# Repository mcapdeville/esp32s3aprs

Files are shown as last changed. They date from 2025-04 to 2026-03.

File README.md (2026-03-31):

# ESP32s3APRS

The ESP32s3APRS project aims to develop an open-source APRS (Automatic Packet Reporting System) beacon/tracker/logger, USB kiss TNC , USB audio FM tranceiver with Micropython shell based on the ESP32-S3 microcontroller.

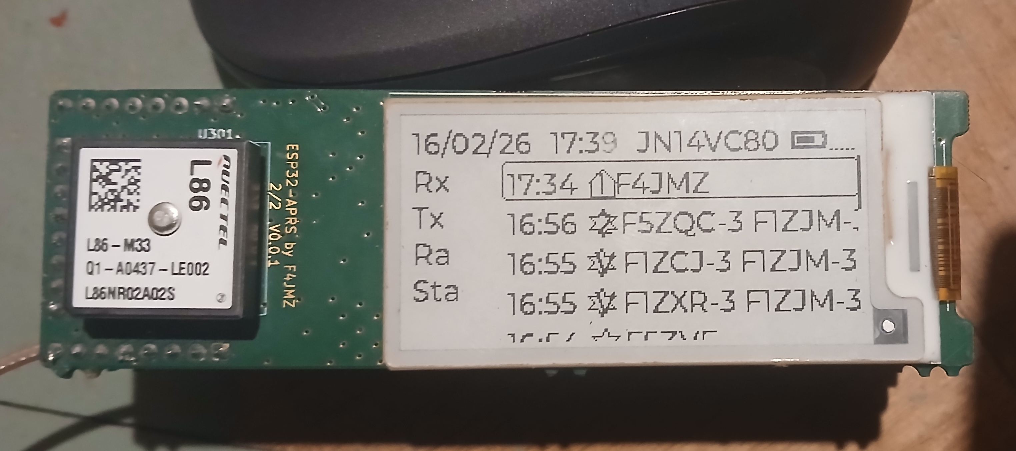
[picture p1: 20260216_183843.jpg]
ESP32s3APRS top view Top view


## Project Overview

The ESP32s3APRS is a comprehensive solution that combines hardware and software components to create a versatile packet radio. The main features include:

- **APRS and AX.25 Capabilities**: The device can transmit and receive APRS and AX.25 frames, allowing for bidirectional communication over radio.
- **USB Connectivity**: The tracker connects to a computer via USB, providing two CDC-ACM ports:
  - One port for a TNC KISS protocol interface
  - One port for a MicroPython console
- **UAC2 Audio Support**: The USB implementation includes the UAC2 protocol, enabling direct audio streaming between the device and the computer.
- **GPS**: Integrated GPS with embeded antenna.
- **Sensor Integration**: The tracker can integrate various sensors, to enrich the data transmitted over the APRS network.
- **USB-C battery charger**: can accept power input from 5v to 14V 
- **User Interface**: The device features an e-paper display and three buttons for configuration and control.
- **Power Management**: The system is designed for low power consumption, allowing for extended autonomous operation.

## Hardware Components

The ESP32s3APRS hardware consists of the following main components:

- ESP32-S3 microcontroller
- SA868 radio module
- Quectel L86 GPS receiver
- E-paper display
- 3 buttons
- USB-C battery charger

The schematic and PCB are designed with Kicad (https://www.kicad.org).
The hardware design files are distributed under the CERN-OHL-S v2 license (or later)

## Software

The software for the ESP32s3APRS is released under the GPL v3 (or later) license. It includes:

- Embedded firmware for the ESP32-S3
- APRS and AX.25 frame processing
- Data storage in flash memory
- Configuration via the user interface and MicroPython console

## Getting Started

To get started with the ESP32s3APRS project, please follow these steps:

1. Clone the repository: `git clone https://github.com/mcapdeville/esp32s3aprs.git`
2. Change to project directory: cd esp32s3aprs
3. Initialize submodules : ./init.sh

## Compile

From the project directory :

1. Load the environment variables: . ./esp-idf/export.sh
2. Compile the project: idf.py build

## Flash the device

1. Put the switch on 'Boot' position
2. Connect USB cable
3. Run: idf.py flash

## Contributing

The ESP32s3APRS project welcomes contributions from the community. You can contribute by:

- Reporting bugs or issues
- Suggesting new features or improvements
- Submitting pull requests for code or documentation changes

## License

The ESP32s3APRS software is licensed under the GPL v3 (or later) license.
The hardware design files are licensed under the CERN-OHL-S v2 license.
See the `LICENSE-GPL-V3.txt` and `LICENSE-CERN-OHL-S-V2.txt` files for more details.

## Acknowledgments

The ESP32s3APRS project was created by Marc CAPDEVILLE (F4JMZ).

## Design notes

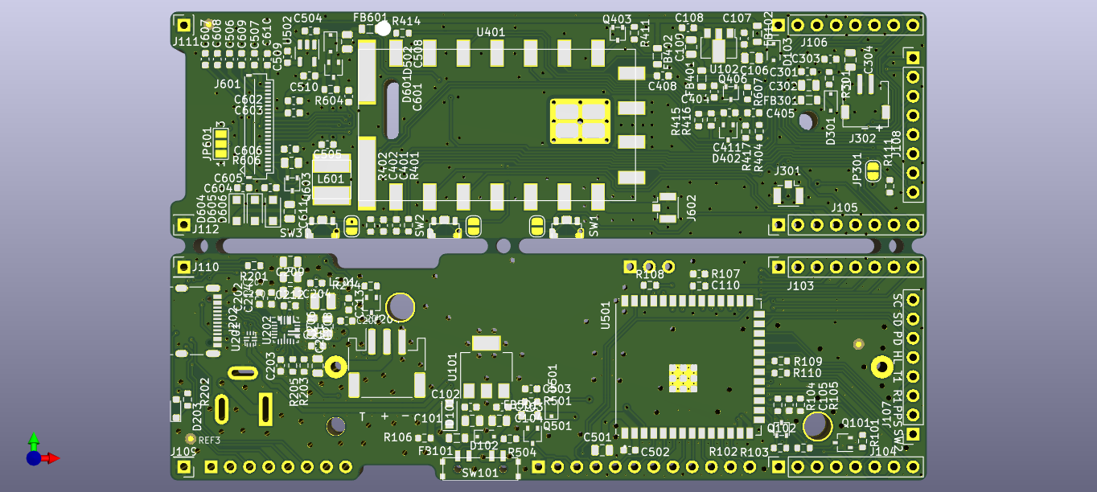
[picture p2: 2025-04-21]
hardware/ESP32s3APRS-top.png

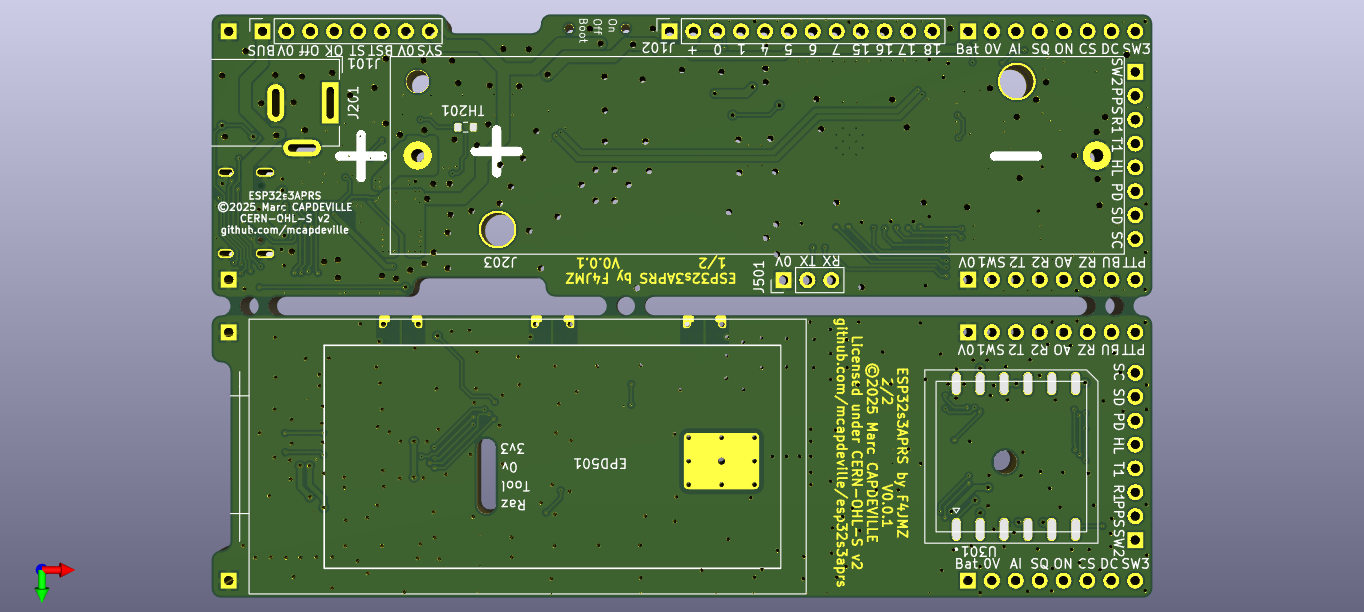
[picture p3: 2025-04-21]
hardware/ESP32s3APRS-bottom.png

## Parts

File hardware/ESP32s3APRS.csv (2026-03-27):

Reference | Qty | Value | Mouser | Radiospares | Farnell
C101,C104,C106,C109,C201,C206,C207,C208,C209,C210,C302,C304,C501 | 13 | 10µF_0805 | 963-TMK212BBJ106MG-T | 184-3756
C102,C103,C107,C108,C204,C211,C212,C213,C214,C301,C303,C404,C408,C411,C502,C504,C506,C507,C601,C603 | 20 | 100nF_0603 | 963-UMK107B7104KAHT | 184-3685
C105 | 1 | 15nF_0603 | 710-885012206090 | 839-2969
C110,C402 | 2 | 4.7nF_50V_0603 | 80-C0603C472K5R | 264-4589
C202,C203,C205 | 3 | 2.2µF_0603 | 963-UMK107BBJ225KA-T | 103-4115
C401 | 1 | 220nF_0603 | 963-UMK107B7224KAHT | 788-2997
C405 | 1 | 68nF_0603 | 710-885012206094 | 839-2978
C503,C505,C510,C602,C604,C605,C606,C607,C608,C609,C610 | 11 | 1µF_0603 | 963-UMK107BJ105KA-T | 103-4112
C508,C611 | 2 | 4.7µF_0805 | 81-GRM21BR61H475KE1L | 113-8707
C509 | 1 | 10nF_50V_0603
D101,D604,D605,D606 | 4 | SS2040FL_SOD123F | 241-SS2040FLAUR100A1
D102,D103,D301,D501,D502 | 5 | BAT54J_SOD323F | 771-BAT54J115
D203 | 1 | APA2107LZGCK | 604-APA2107LZGCK
D402,D601 | 2 | BAT54SW_SOT323 | 771-BAT54SW-T/R | 380-1216
EPD501 | 1 | GDEY0213B74
FB101,FB102,FB301,FB401,FB402,FB501,FB601 | 7 | WE-CBF_742792031 | 710-742792031 | 669-4092
J101 | 1 | SSQ-108-01-G-S | 200-SSQ10801GS
J102 | 1 | SSQ-112-01-G-S | 200-SSQ11201GS
J103,J104,J107 | 3 | SLW-108-01-G-S | 200-SLW10801GS
J105,J106,J108 | 3 | HTSW-108-07-G-S | 200-HTSW10807GS
J109,J110 | 2 | HTSW-101-07-G-S | 200-HTSW10107GS
J111,J112 | 2 | SLW-101-01-G-S | 200-SLW10101GS
J201 | 1 | WR-DC-694108301002 | 710-694108301002
J202 | 1 | USB4105-GF-A-120 | 640-USB4105-GF-A-120
J203 | 1 | Keystone_1043P | 534-1043
J204 | 1 | S3B-PH-SM4-TB | 306-S3BPHSM4TBLFSN | 688-1357
J301,J602 | 2 | U.FL-R-SMT-1 | 798-U.FL-R-SMT-110 | 557-981
J302 | 1 | S2B-ZR-SM4A-TF | 306-S2BZRSM4ATFLFSN | 762-0875 | 1830920
J501 | 1 | HTSW-103-07-G-S | 200-HTSW10307GS | 180-2117
J601 | 1 | FH34SRJ-24S-05SH | 798-FH34SRJ24S05SH99 | 136-2403
JP101,JP102,JP103 | 3 | DNP 0603
JP301 | 1 | SolderJumper_2_Open
JP601 | 1 | SolderJumper_3_Bridged12
L201 | 1 | DFE252012F-1R0M | 81-DFE252012F-1R0MP2 | 230-7900
L601 | 1 | PA4322.103NLT | 673-PA4322.103NLT
Q101,Q201,Q501 | 3 | BC846BW_SOT323 | 771-BC846BW-T/R | 436-7931
Q102,Q406 | 2 | RZF020P01TL | 755-RZF020P01TL
Q403,Q603 | 2 | RTF025N03TL | 755-RTF025N03TL
R101,R201,R204,R504 | 4 | 100K_0603 | 603-RC0603FR-07100KL | 199-5439
R102,R104,R105,R203,R205,R416,R417,R501,R604 | 9 | 10K_0603 | 603-RC0603FR-0710KL | 199-5443
R103,R411,R414 | 3 | 100R_0603 | 603-RC0603FR-07100RL | 199-5441
R106,R111 | 2 | 47K_0603 | 603-RC0603FR-0747KL | 199-5581
R107,R301,R402 | 3 | 1K_0603 | 603-RC0603FR-071KL | 199-5479
R108,R109,R110 | 3 | 470R_0603
R202 | 1 | 2K2_0603 | 603-RC0603FR-072K2L | 199-5518
R401 | 1 | 75K_0603 | 603-RC0603FR-0775KL | 199-5631
R404 | 1 | 22R_0603 | 603-RC0603FR-0722RL | 199-5504
R415 | 1 | 17K8_0603 | 603-RC0603FR-0717K8L | 122-9032
R606 | 1 | 0R47_0805 | 71-RCWE0805R470FKEA | 199-6016
R607 | 1 | R_DNP_0603
REF1,REF2,REF3 | 3 | Fiducial
SW1,SW2,SW3 | 3 | SKTDLDE010 | 688-SKTDLDE010 | 917-3839
SW101 | 1 | PCM13SMTR | 611-PCM13SMTR
TH201 | 1 | NTC 10K 1% 0603 | 594-NTCS0603E3103FMT | 684-1264
U101 | 1 | AP7361C-33E_SOT223 | 621-AP7361C-33E-13
U102 | 1 | XC6206P332PR_SOT89 | 865-XC6206P332PR-G
U201 | 1 | PI3USB102G | 729-PI3USB102GZLEX
U202 | 1 | MAX77757CEFG+ | 700-MAX77757JEFG420
U301 | 1 | L86-M33 | 277-L86-M33 | 908-4114
U401 | 1 | SA868
U501 | 1 | ESP32-S3-WROOM-1U | 356-ESP32S3WM1UN16R2
U502 | 1 | LP2985-3.3

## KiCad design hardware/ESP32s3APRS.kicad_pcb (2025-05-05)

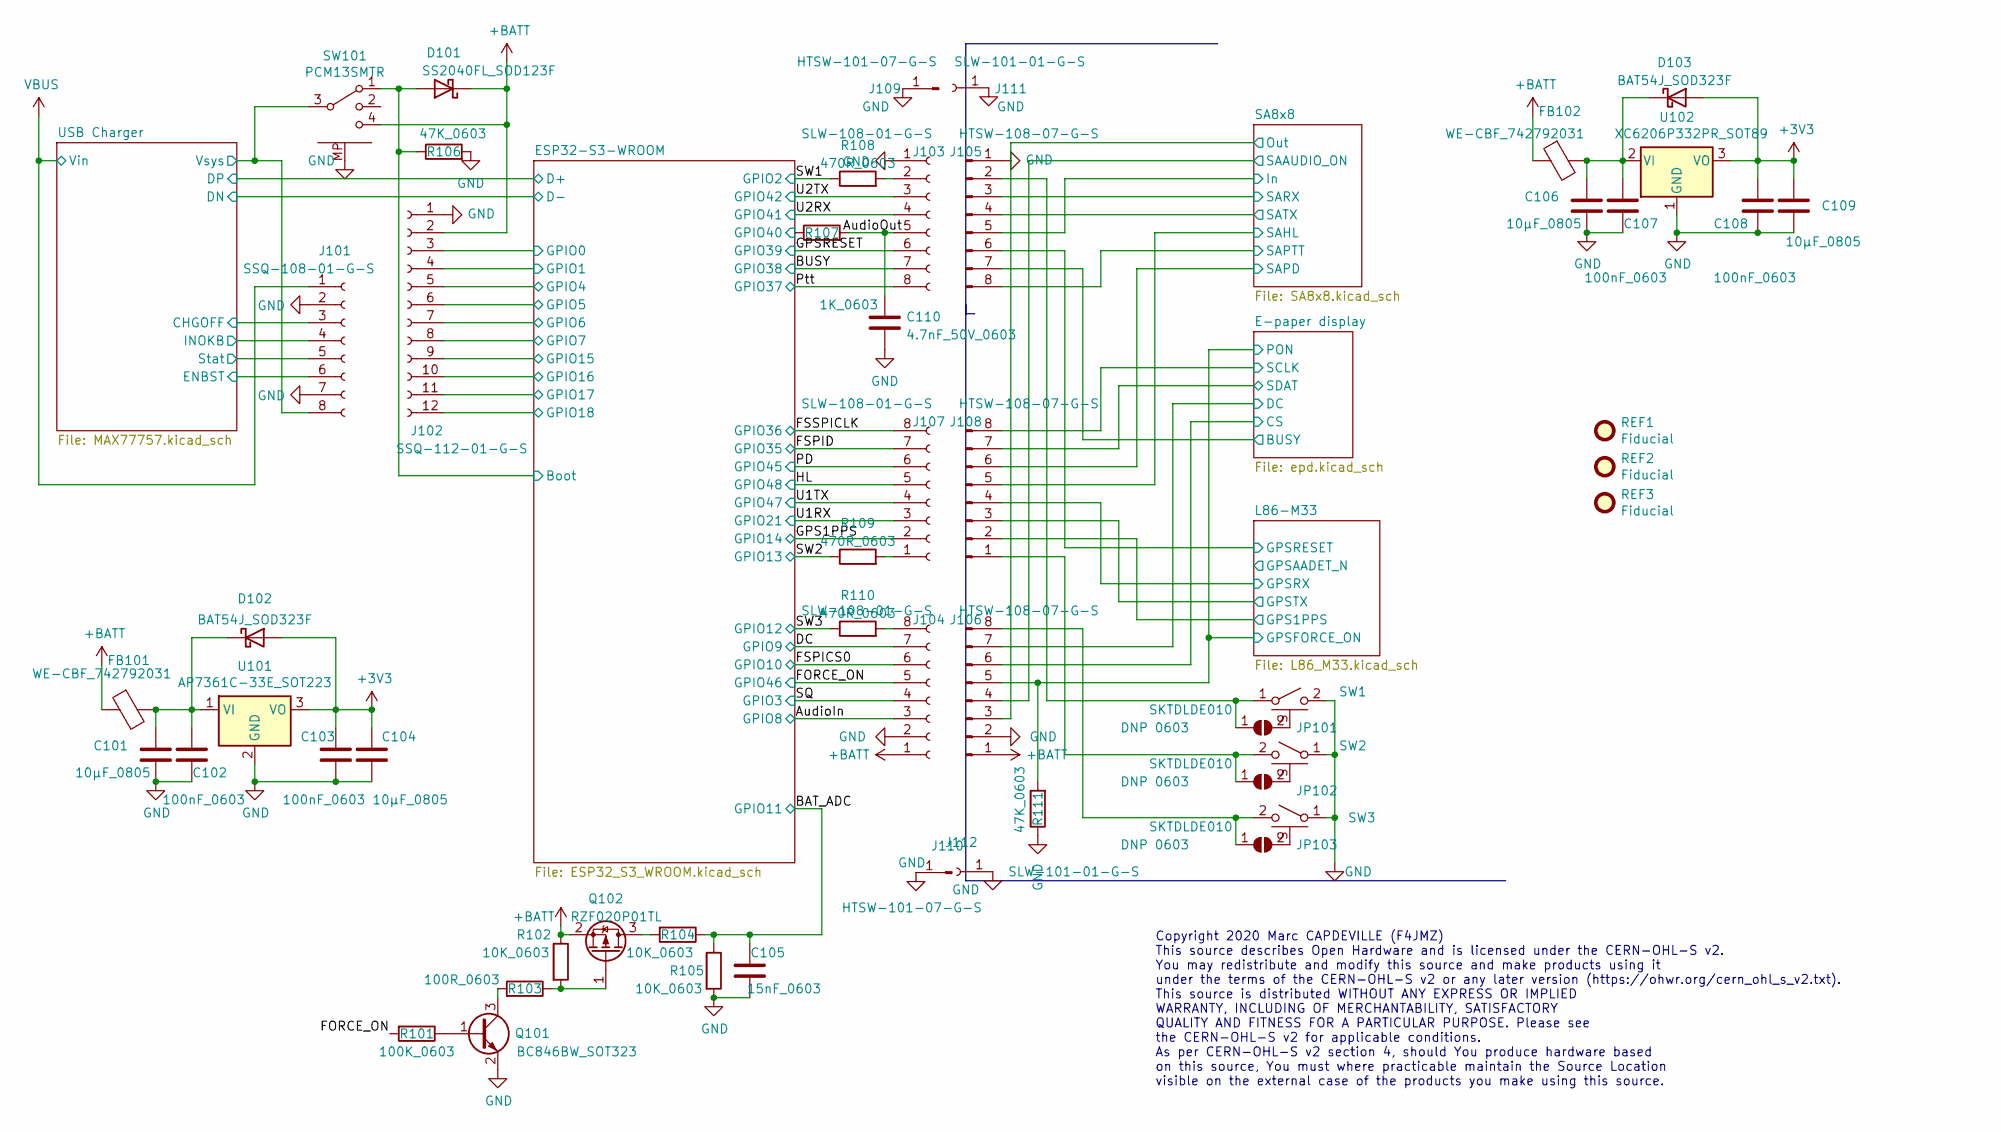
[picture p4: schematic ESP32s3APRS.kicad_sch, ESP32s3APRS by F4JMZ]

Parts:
C101, C104, C106, C109: 10µF_0805; C_0805_2012Metric; Mouser 963-TMK212BBJ106MG-T
C102, C103, C107, C108: 100nF_0603; C_0603_1608Metric; Mouser 963-UMK107B7104KAHT
C105: 15nF_0603; C_0603_1608Metric; Mouser 710-885012206090
C110: 4.7nF_50V_0603; C_0603_1608Metric; Mouser 80-C0603C472K5R
D101: SS2040FL_SOD123F; D_SOD-123F; Mouser 241-SS2040FLAUR100A1
D102, D103: BAT54J_SOD323F; D_SOD-323F; Mouser 771-BAT54J115
FB101, FB102: WE-CBF_742792031; L_0805_2012Metric; Mouser 710-742792031
J101: SSQ-108-01-G-S; PinSocket_1x08_P2.54mm_Vertical; Mouser 200-SSQ10801GS
J102: SSQ-112-01-G-S; PinSocket_1x12_P2.54mm_Vertical; Mouser 200-SSQ11201GS
J103, J104, J107: SLW-108-01-G-S; PinSocket_1x08_P2.54mm_Vertical; Mouser 200-SLW10801GS
J105, J106, J108: HTSW-108-07-G-S; PinHeader_1x08_P2.54mm_Vertical; Mouser 200-HTSW10807GS
J109, J110: HTSW-101-07-G-S; PinHeader_1x01_P2.54mm_Vertical; Mouser 200-HTSW10107GS
J111, J112: SLW-101-01-G-S; PinSocket_1x01_P2.54mm_Vertical; Mouser 200-SLW10101GS
JP101, JP102, JP103: DNP 0603; R_0603_1608Metric_Pad0.98x0.95mm_HandSolder
Q101: BC846BW_SOT323; SOT-323_SC-70; Mouser 771-BC846BW-T/R
Q102: RZF020P01TL; SOT-323T_SC-113A; Mouser 755-RZF020P01TL
R101: 100K_0603; R_0603_1608Metric; Mouser 603-RC0603FR-07100KL
R102, R104, R105: 10K_0603; R_0603_1608Metric; Mouser 603-RC0603FR-0710KL
R103: 100R_0603; R_0603_1608Metric; Mouser 603-RC0603FR-07100RL
R106, R111: 47K_0603; R_0603_1608Metric; Mouser 603-RC0603FR-0747KL
R107: 1K_0603; R_0603_1608Metric; Mouser 603-RC0603FR-071KL
R108, R109, R110: 470R_0603; R_0603_1608Metric
REF1, REF2, REF3: Fiducial; Fiducial_0.75mm_Mask1.5mm
SW1, SW2, SW3: SKTDLDE010; Mouser 688-SKTDLDE010
SW101: PCM13SMTR; SW_PCM13SMTR _SP3T; Mouser 611-PCM13SMTR
U101: AP7361C-33E_SOT223; SOT-223-3_TabPin2; Mouser 621-AP7361C-33E-13
U102: XC6206P332PR_SOT89; SOT-89-3; Mouser 865-XC6206P332PR-G

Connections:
+3V3: C103.1, C104.1, C108.1, C109.1, D102.2 (A), D103.2 (A), U101.3 (VO), U102.3 (VO); also elsewhere on the board
+BATT: D101.1 (K), FB101.1, FB102.1, J102.2, J104.1, J106.1, Q102.2 (S), R102.1, SW101.4; also elsewhere on the board
/AudioIn: J104.3; also elsewhere on the board
/BAT_ADC: C105.1, R104.1, R105.1; also elsewhere on the board
/BUSY: J103.7; also elsewhere on the board
/DC: J104.7; also elsewhere on the board
/E-paper display/BUSY: J105.7; also elsewhere on the board
/E-paper display/CS: J106.6; also elsewhere on the board
/E-paper display/DC: J106.7; also elsewhere on the board
/E-paper display/PON: J106.5, R111.2; also elsewhere on the board
/E-paper display/SCLK: J108.8; also elsewhere on the board
/E-paper display/SDAT: J108.7; also elsewhere on the board
/ESP32-S3-WROOM/Boot: D101.2 (A), R106.1, SW101.1; also elsewhere on the board
/ESP32-S3-WROOM/GPIO0: J102.3; also elsewhere on the board
/ESP32-S3-WROOM/GPIO1: J102.4; also elsewhere on the board
/ESP32-S3-WROOM/GPIO4: J102.5; also elsewhere on the board
/ESP32-S3-WROOM/GPIO5: J102.6; also elsewhere on the board
/ESP32-S3-WROOM/GPIO6: J102.7; also elsewhere on the board
/ESP32-S3-WROOM/GPIO7: J102.8; also elsewhere on the board
/ESP32-S3-WROOM/GPIO15: J102.9; also elsewhere on the board
/ESP32-S3-WROOM/GPIO16: J102.10; also elsewhere on the board
/ESP32-S3-WROOM/GPIO17: J102.11; also elsewhere on the board
/ESP32-S3-WROOM/GPIO18: J102.12; also elsewhere on the board
/ESP32-S3-WROOM/GPIO40: R107.1; also elsewhere on the board
/FORCE_ON: J104.5, R101.2; also elsewhere on the board
/FSPICS0: J104.6; also elsewhere on the board
/FSPID: J107.7; also elsewhere on the board
/FSSPICLK: J107.8; also elsewhere on the board
/GPS1PPS: J107.2; also elsewhere on the board
/GPSRESET: J103.6; also elsewhere on the board
/HL: J107.5; also elsewhere on the board
/L86-M33/GPS1PPS: J108.2; also elsewhere on the board
/L86-M33/GPSRESET: J105.6; also elsewhere on the board
/L86-M33/GPSRX: J108.4; also elsewhere on the board
/L86-M33/GPSTX: J108.3; also elsewhere on the board
/PD: J107.6; also elsewhere on the board
/Ptt: J103.8; also elsewhere on the board
/SA8x8/In: J105.5; also elsewhere on the board
/SA8x8/Out: J106.3; also elsewhere on the board
/SA8x8/SAAUDIO_ON: J106.4; also elsewhere on the board
/SA8x8/SAHL: J108.5; also elsewhere on the board
/SA8x8/SAPD: J108.6; also elsewhere on the board
/SA8x8/SAPTT: J105.8; also elsewhere on the board
/SA8x8/SARX: J105.3; also elsewhere on the board
/SA8x8/SATX: J105.4; also elsewhere on the board
/SQ: J104.4; also elsewhere on the board
/SW1: R108.1; also elsewhere on the board
/SW2: R109.1; also elsewhere on the board
/SW3: R110.1; also elsewhere on the board
/U1RX: J107.3; also elsewhere on the board
/U1TX: J107.4; also elsewhere on the board
/U2RX: J103.4; also elsewhere on the board
/U2TX: J103.3; also elsewhere on the board
/USB Charger/CHGOFF: J101.3; also elsewhere on the board
/USB Charger/ENBST: J101.6; also elsewhere on the board
/USB Charger/INOKB: J101.4; also elsewhere on the board
/USB Charger/Stat: J101.5; also elsewhere on the board
/USB Charger/Vsys: J101.8, SW101.3; also elsewhere on the board
GND: C101.2, C102.2, C103.2, C104.2, C105.2, C106.2, C107.2, C108.2, C109.2, C110.2, J101.2, J101.7, J102.1, J103.1, J104.2, J105.1, J106.2, J109.1, J110.1, J111.1, J112.1, Q101.2 (E), R105.2, R106.2, R111.1, SW1.2 (B), SW2.1 (A), SW3.1 (A), SW101.MP, U101.2 (GND), U102.1 (GND); also elsewhere on the board
unnamed: C101.1, C102.1, D102.1 (K), FB101.2, U101.1 (VI)
unnamed: C106.1, C107.1, D103.1 (K), FB102.2, U102.2 (VI)
unnamed: C110.1, J103.5, R107.2
unnamed: J103.2, R108.2
unnamed: J104.8, R110.2
unnamed: J105.2, JP101.1 (A), SW1.1 (A)
unnamed: J106.8, JP103.1 (A), SW3.2 (B)
unnamed: J107.1, R109.2
unnamed: J108.1, JP102.1 (A), SW2.2 (B)
unnamed: JP101.2 (B), SW1.S (MP)
unnamed: JP102.2 (B), SW2.S (MP)
unnamed: JP103.2 (B), SW3.S (MP)
unnamed: Q101.1 (B), R101.1
unnamed: Q101.3 (C), R103.2
unnamed: Q102.1 (G), R102.2, R103.1
unnamed: Q102.3 (D), R104.2
VBUS: J101.1; also elsewhere on the board

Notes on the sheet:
Copyright 2020 Marc CAPDEVILLE (F4JMZ) This source describes Open Hardware and is licensed under the CERN-OHL-S v2. You may redistribute and modify this source and make products using it under the terms of the CERN-OHL-S v2 or any later version (https://ohwr.org/cern_ohl_s_v2.txt). This source is d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

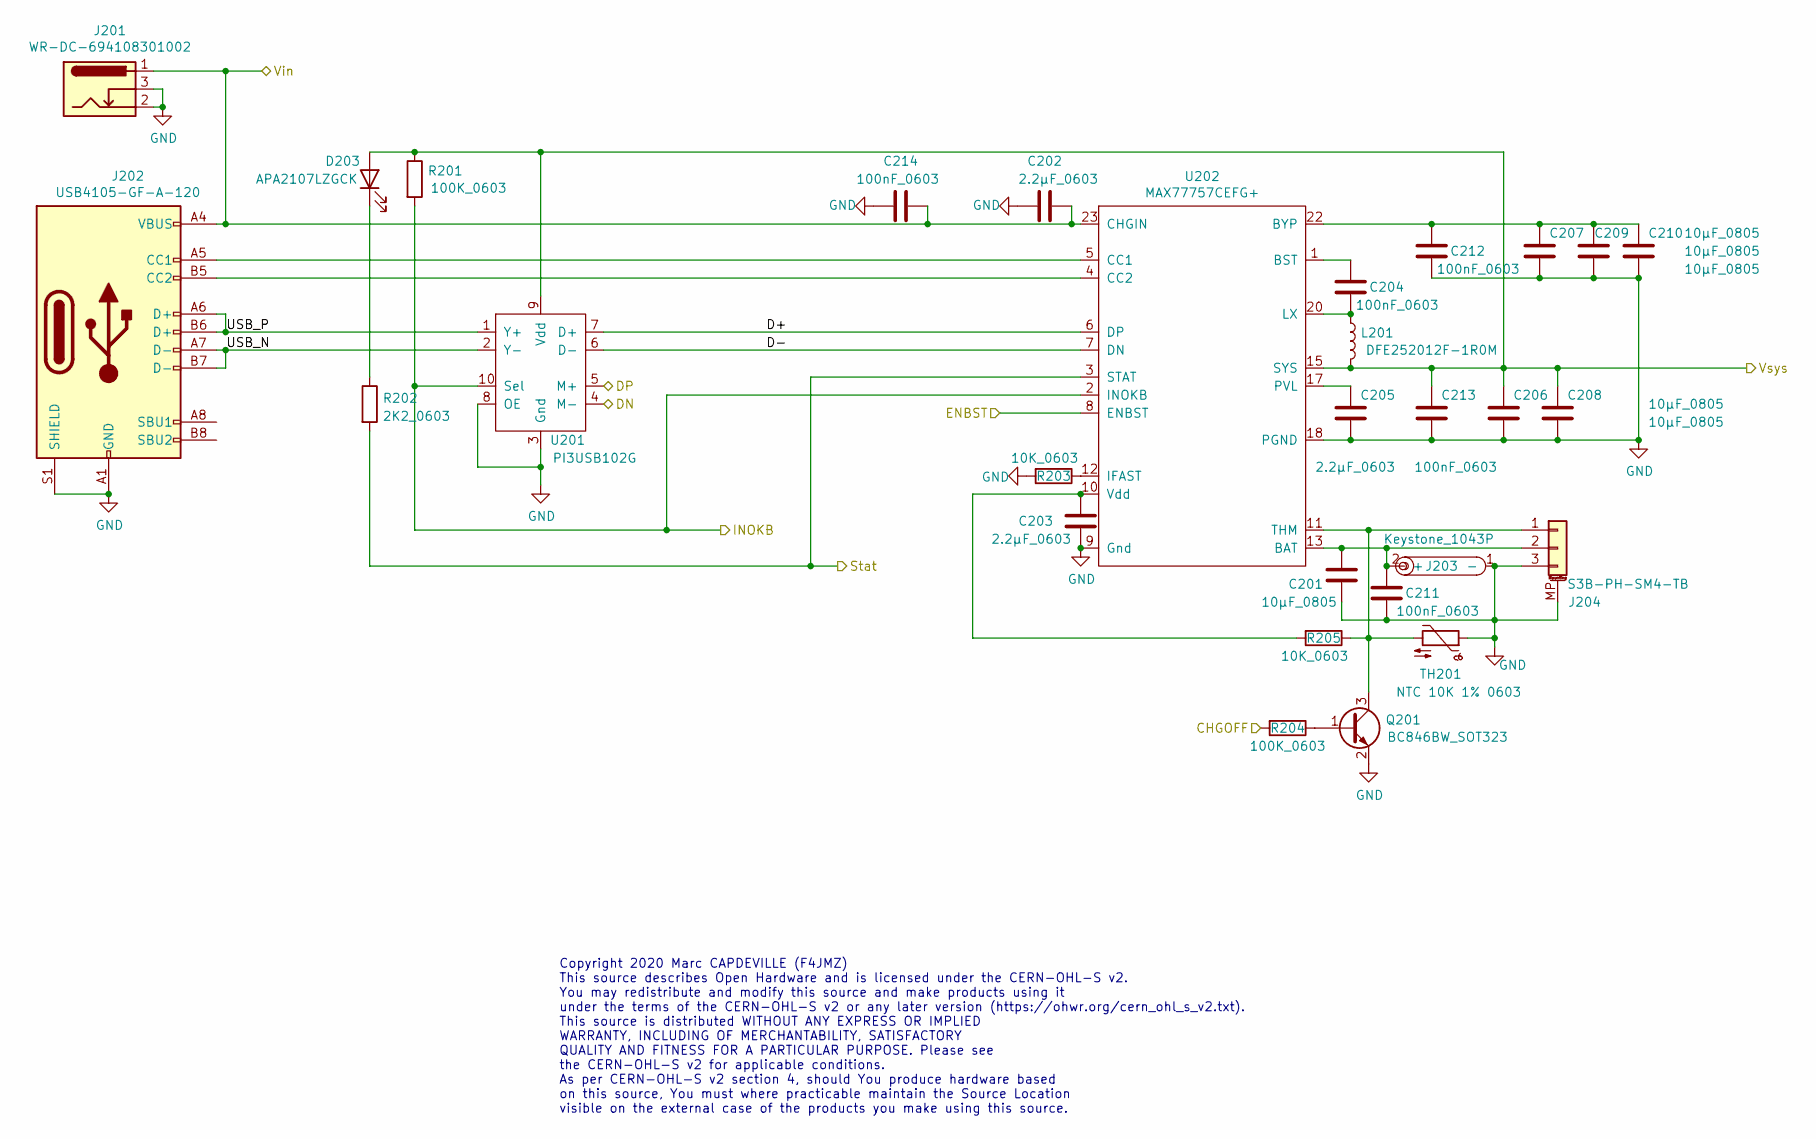
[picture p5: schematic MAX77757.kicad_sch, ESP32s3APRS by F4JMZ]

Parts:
C201, C206, C207, C208, C209, C210: 10µF_0805; C_0805_2012Metric; Mouser 963-TMK212BBJ106MG-T
C202, C203, C205: 2.2µF_0603; C_0603_1608Metric; Mouser 963-UMK107BBJ225KA-T
C204, C211, C212, C213, C214: 100nF_0603; C_0603_1608Metric; Mouser 963-UMK107B7104KAHT
D203: APA2107LZGCK; SIDELED_APA2107; Mouser 604-APA2107LZGCK
J201: WR-DC-694108301002; BarrelJack_Wuerth_6941xx301002; Mouser 710-694108301002
J202: USB4105-GF-A-120; USB_C_Receptacle_GCT_4105; Mouser 640-USB4105-GF-A-120
J203: Keystone_1043P; Keystone-1043; Mouser 534-1043
J204: S3B-PH-SM4-TB; JST_PH_S3B-PH-SM4-TB_1x03-1MP_P2.00mm_Horizontal; Mouser 306-S3BPHSM4TBLFSN
L201: DFE252012F-1R0M; L_1008_2520Metric; Mouser 81-DFE252012F-1R0MP2
Q201: BC846BW_SOT323; SOT-323_SC-70; Mouser 771-BC846BW-T/R
R201, R204: 100K_0603; R_0603_1608Metric; Mouser 603-RC0603FR-07100KL
R202: 2K2_0603; R_0603_1608Metric; Mouser 603-RC0603FR-072K2L
R203, R205: 10K_0603; R_0603_1608Metric; Mouser 603-RC0603FR-0710KL
TH201: NTC 10K 1% 0603; R_0603_1608Metric; Mouser 594-NTCS0603E3103FMT
U201: PI3USB102G; TQFN-10_1.3x1.6mm_P0.4mm; Mouser 729-PI3USB102GZLEX
U202: MAX77757CEFG+; FC2QFN-24_3x3_Pitch0.4mm; Mouser 700-MAX77757JEFG420

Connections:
/ESP32-S3-WROOM/D+: U201.5 (M+); also elsewhere on the board
/ESP32-S3-WROOM/D-: U201.4 (M-); also elsewhere on the board
/USB Charger/CHGOFF: R204.2; also elsewhere on the board
/USB Charger/D+: U201.7 (D+), U202.6 (DP)
/USB Charger/D-: U201.6 (D-), U202.7 (DN)
/USB Charger/ENBST: U202.8 (ENBST); also elsewhere on the board
/USB Charger/INOKB: R201.2, U201.10 (Sel), U202.2 (INOKB); also elsewhere on the board
/USB Charger/Stat: R202.2, U202.3 (STAT); also elsewhere on the board
/USB Charger/USB_N: J202.A7 (D-), J202.B7 (D-), U201.2 (Y-)
/USB Charger/USB_P: J202.A6 (D+), J202.B6 (D+), U201.1 (Y+)
/USB Charger/Vsys: C206.1, C208.1, C213.1, D203.2 (A), L201.2, R201.1, U201.9 (Vdd), U202.15 (SYS), U202.16 (SYS); also elsewhere on the board
GND: C201.2, C202.2, C203.2, C205.2, C206.2, C207.2, C208.2, C209.2, C210.2, C211.2, C212.2, C213.2, C214.2, J201.2, J201.3, J202.A1 (GND), J202.A12 (GND), J202.B1 (GND), J202.B12 (GND), J202.S1 (SHIELD), J203.1 (-), J204.3, J204.MP (MountPin), Q201.2 (E), R203.2, TH201.1, U201.3 (Gnd), U201.8 (OE), U202.9 (Gnd), U202.18 (PGND), U202.19 (PGND); also elsewhere on the board
unnamed: C201.1, C211.1, J203.2 (+), J204.2, U202.13 (BAT), U202.14 (BAT)
unnamed: C203.1, R205.2, U202.10 (Vdd)
unnamed: C204.1, U202.1 (BST)
unnamed: C204.2, L201.1, U202.20 (LX), U202.21 (LX)
unnamed: C205.1, U202.17 (PVL)
unnamed: C207.1, C209.1, C210.1, C212.1, U202.22 (BYP)
unnamed: D203.1 (K), R202.1
unnamed: J202.A5 (CC1), U202.5 (CC1)
unnamed: J202.B5 (CC2), U202.4 (CC2)
unnamed: J204.1, Q201.3 (C), R205.1, TH201.2, U202.11 (THM)
unnamed: Q201.1 (B), R204.1
unnamed: R203.1, U202.12 (IFAST)
VBUS: C202.1, C214.1, J201.1, J202.A4 (VBUS), J202.A9 (VBUS), J202.B4 (VBUS), J202.B9 (VBUS), U202.23 (CHGIN), U202.24 (CHGIN); also elsewhere on the board

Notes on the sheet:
Copyright 2020 Marc CAPDEVILLE (F4JMZ) This source describes Open Hardware and is licensed under the CERN-OHL-S v2. You may redistribute and modify this source and make products using it under the terms of the CERN-OHL-S v2 or any later version (https://ohwr.org/cern_ohl_s_v2.txt). This source is d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

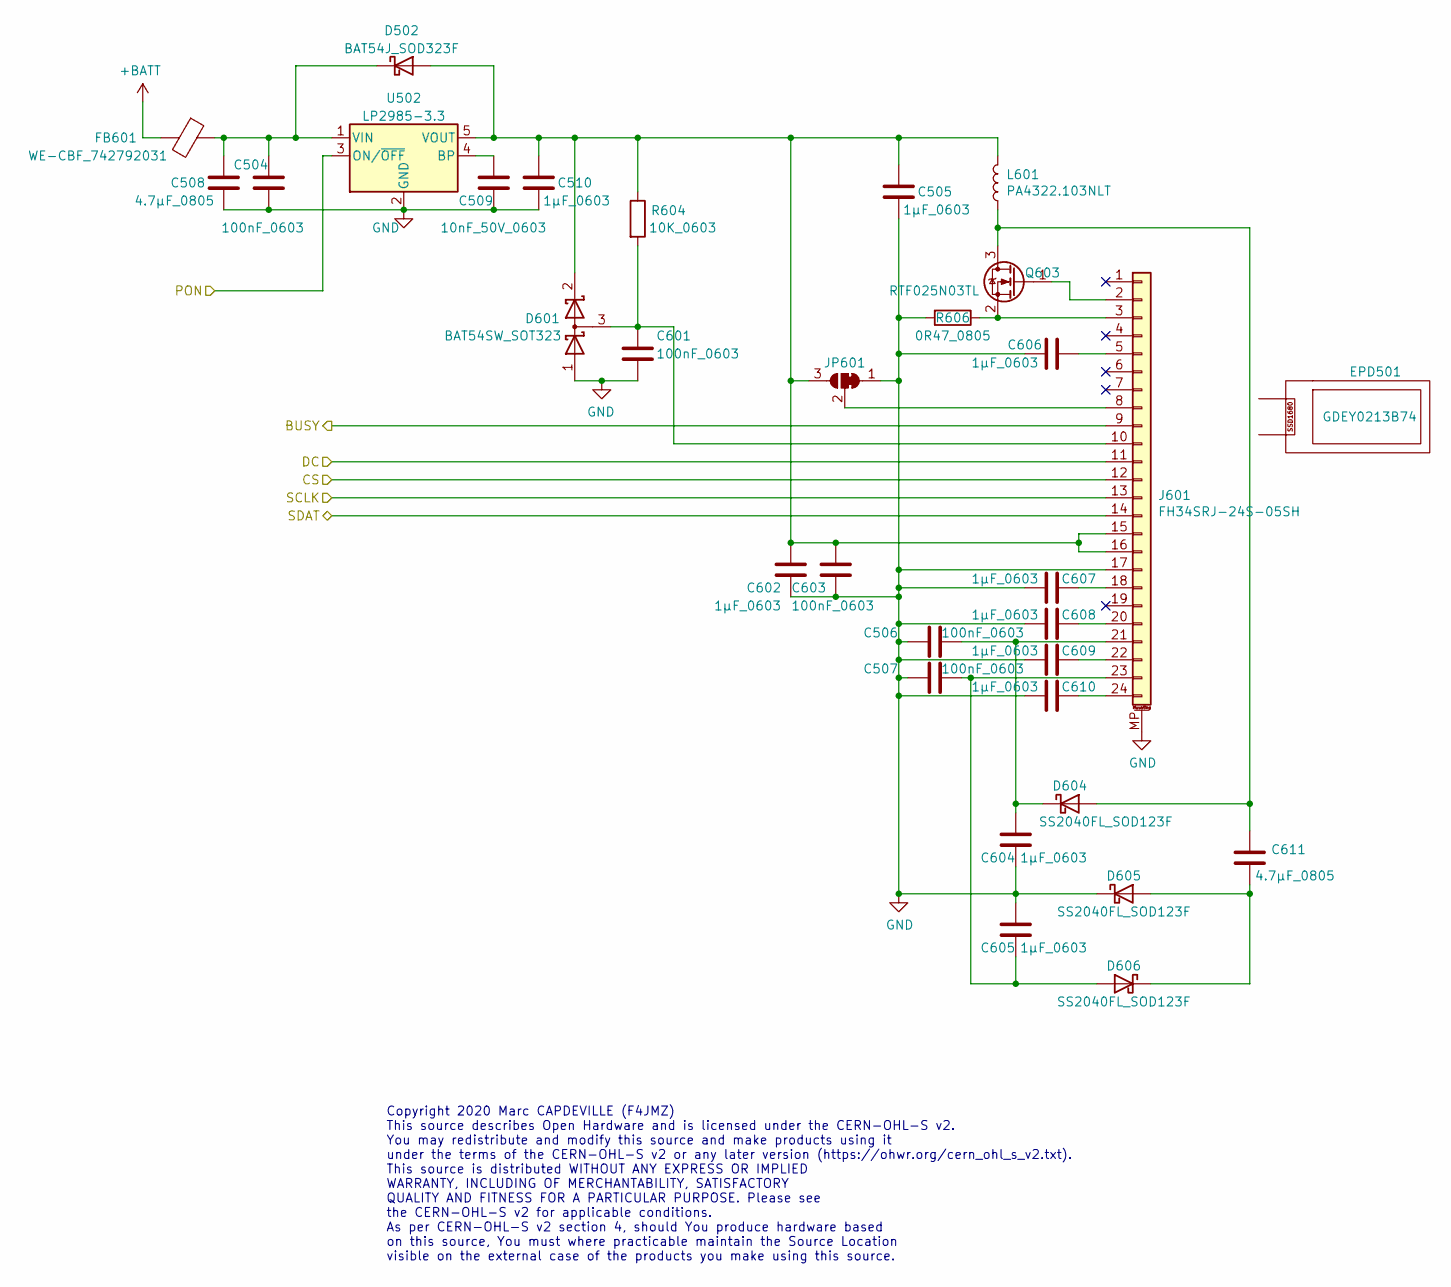
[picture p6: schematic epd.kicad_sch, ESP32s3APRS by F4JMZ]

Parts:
C504, C506, C507, C601, C603: 100nF_0603; C_0603_1608Metric; Mouser 963-UMK107B7104KAHT
C505, C510, C602, C604, C605, C606, C607, C608, C609, C610: 1µF_0603; C_0603_1608Metric; Mouser 963-UMK107BJ105KA-T
C508, C611: 4.7µF_0805; C_0805_2012Metric; Mouser 81-GRM21BR61H475KE1L
C509: 10nF_50V_0603; C_0603_1608Metric
D502: BAT54J_SOD323F; D_SOD-323F; Mouser 771-BAT54J115
D601: BAT54SW_SOT323; SOT-323_SC-70; Mouser 771-BAT54SW-T/R
D604, D605, D606: SS2040FL_SOD123F; D_SOD-123F; Mouser 241-SS2040FLAUR100A1
EPD501: GDEY0213B74; GDEY0213B74_2.13_EPD
FB601: WE-CBF_742792031; L_0805_2012Metric; Mouser 710-742792031
J601: FH34SRJ-24S-05SH; Hirose_FH34-24SRJ-0.5SH_1x24-1MP_P0.50mm_Horizontal; Mouser 798-FH34SRJ24S05SH99
JP601: SolderJumper_3_Bridged12; SolderJumper-3_P1.3mm_Bridged2Bar12_Pad1.0x1.5mm_NumberLabe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
L601: PA4322.103NLT; Inductor_Pulse_PA4322.xxxNLT_5.1x5.1; Mouser 673-PA4322.103NLT
Q603: RTF025N03TL; SOT-323T_SC-113A; Mouser 755-RTF025N03TL
R604: 10K_0603; R_0603_1608Metric; Mouser 603-RC0603FR-0710KL
R606: 0R47_0805; R_0805_2012Metric; Mouser 71-RCWE0805R470FKEA
U502: LP2985-3.3; SOT-23-5

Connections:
+BATT: FB601.2; also elsewhere on the board
/E-paper display/BUSY: J601.9; also elsewhere on the board
/E-paper display/CS: J601.12; also elsewhere on the board
/E-paper display/DC: J601.11; also elsewhere on the board
/E-paper display/PON: U502.3 (ON/~OFF); also elsewhere on the board
/E-paper display/SCLK: J601.13; also elsewhere on the board
/E-paper display/SDAT: J601.14; also elsewhere on the board
GND: C504.1, C505.1, C506.1, C507.1, C508.2, C509.2, C510.1, C601.2, C602.1, C603.2, C604.1, C605.2, C606.2, C607.2, C608.2, C609.2, C610.2, D601.1 (A), D605.1 (K), J601.17, J601.MP (MountPin), JP601.1 (A), R606.2, U502.2 (GND); also elsewhere on the board
unnamed: C504.2, C508.1, D502.1 (K), FB601.1, U502.1 (VIN)
unnamed: C505.2, C510.2, C602.2, C603.1, D502.2 (A), D601.2 (A), J601.15, J601.16, JP601.3 (B), L601.2, R604.1, U502.5 (VOUT)
unnamed: C506.2, C604.2, D604.1 (K), J601.21
unnamed: C507.2, C605.1, D606.2 (A), J601.23
unnamed: C509.1, U502.4 (BP)
unnamed: C601.1, D601.3 (K), J601.10, R604.2
unnamed: C606.1, J601.5
unnamed: C607.1, J601.18
unnamed: C608.1, J601.20
unnamed: C609.1, J601.22
unnamed: C610.1, J601.24
unnamed: C611.1, D604.2 (A), L601.1, Q603.3 (D)
unnamed: C611.2, D605.2 (A), D606.1 (K)
unnamed: J601.2, Q603.1 (G)
unnamed: J601.3, Q603.2 (S), R606.1
unnamed: J601.8, JP601.2 (C)

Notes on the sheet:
Copyright 2020 Marc CAPDEVILLE (F4JMZ) This source describes Open Hardware and is licensed under the CERN-OHL-S v2. You may redistribute and modify this source and make products using it under the terms of the CERN-OHL-S v2 or any later version (https://ohwr.org/cern_ohl_s_v2.txt). This source is d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

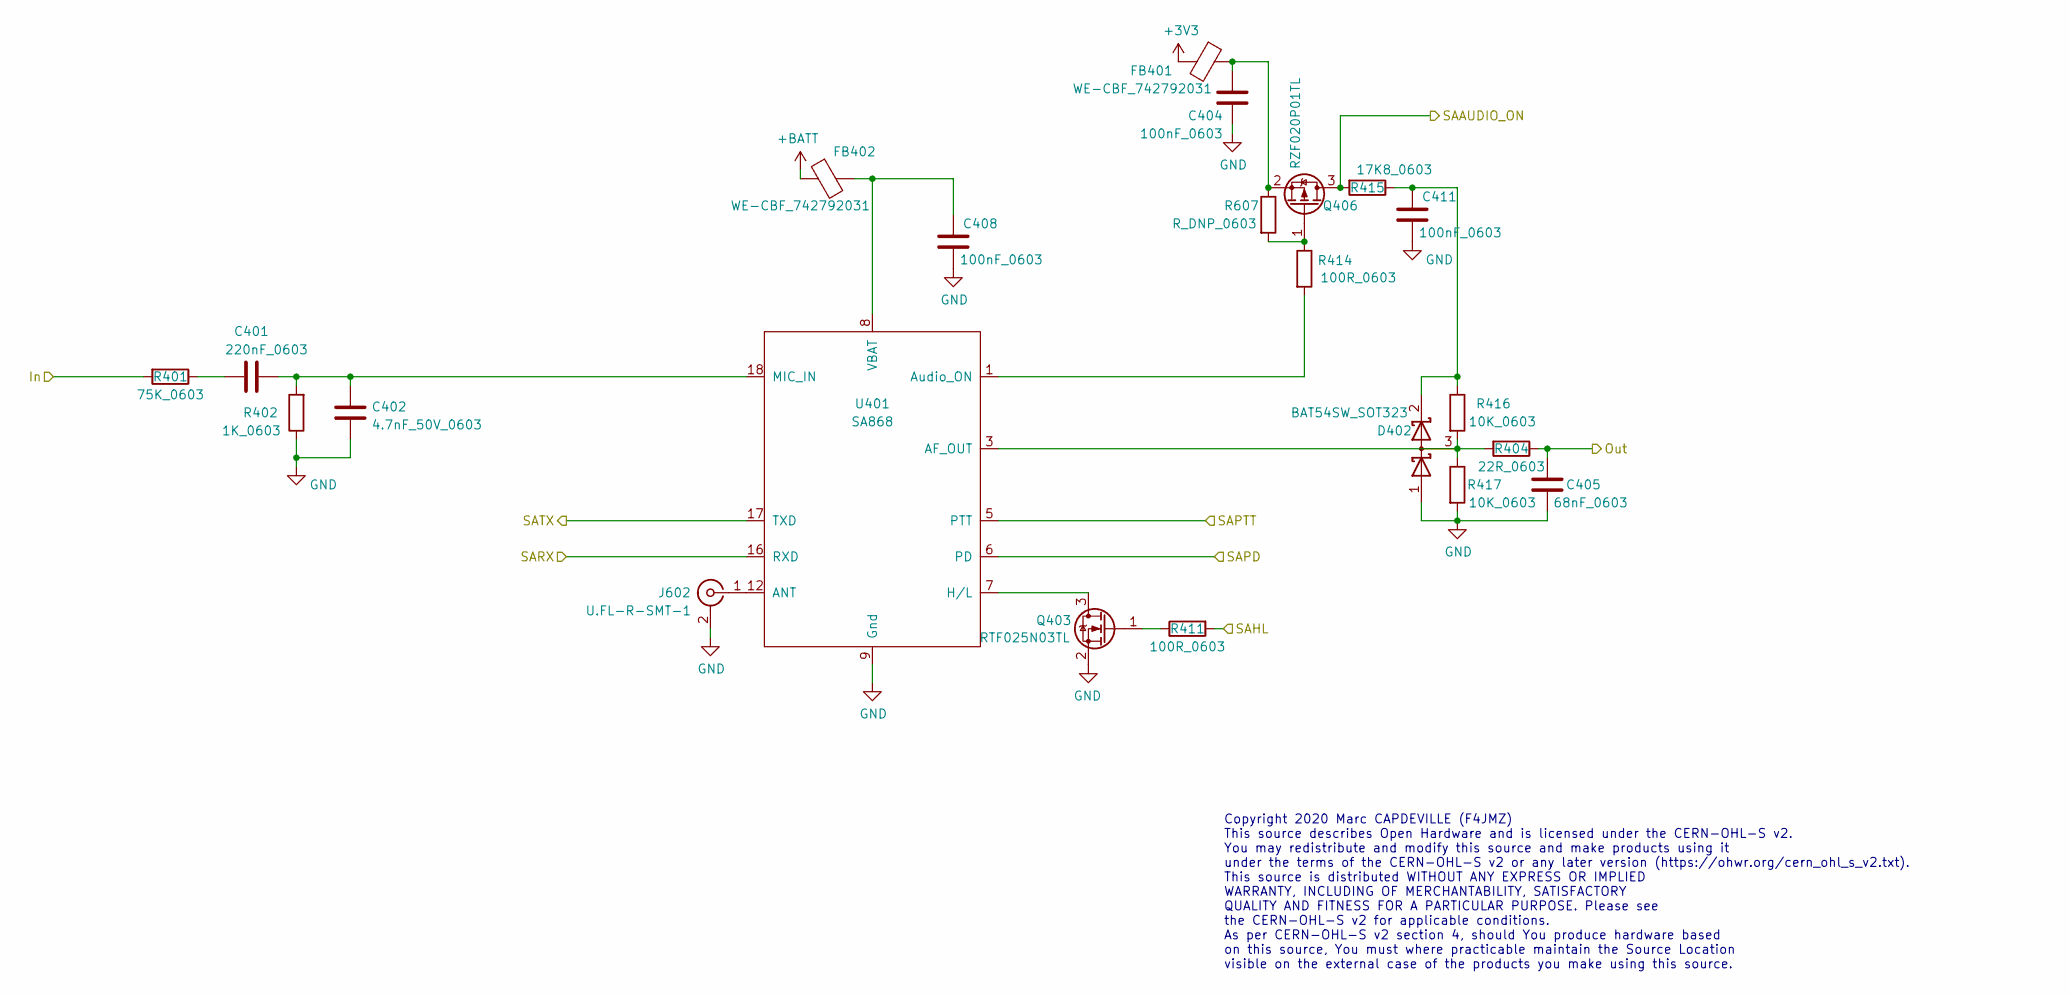
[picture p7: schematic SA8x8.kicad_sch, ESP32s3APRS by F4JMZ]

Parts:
C401: 220nF_0603; C_0603_1608Metric; Mouser 963-UMK107B7224KAHT
C402: 4.7nF_50V_0603; C_0603_1608Metric; Mouser 80-C0603C472K5R
C404, C408, C411: 100nF_0603; C_0603_1608Metric; Mouser 963-UMK107B7104KAHT
C405: 68nF_0603; C_0603_1608Metric; Mouser 710-885012206094
D402: BAT54SW_SOT323; SOT-323_SC-70; Mouser 771-BAT54SW-T/R
FB401, FB402: WE-CBF_742792031; L_0805_2012Metric; Mouser 710-742792031
J602: U.FL-R-SMT-1; U.FL_Hirose_U.FL-R-SMT-1_Vertical; Mouser 798-U.FL-R-SMT-110
Q403: RTF025N03TL; SOT-323T_SC-113A; Mouser 755-RTF025N03TL
Q406: RZF020P01TL; SOT-323T_SC-113A; Mouser 755-RZF020P01TL
R401: 75K_0603; R_0603_1608Metric; Mouser 603-RC0603FR-0775KL
R402: 1K_0603; R_0603_1608Metric; Mouser 603-RC0603FR-071KL
R404: 22R_0603; R_0603_1608Metric; Mouser 603-RC0603FR-0722RL
R411, R414: 100R_0603; R_0603_1608Metric; Mouser 603-RC0603FR-07100RL
R415: 17K8_0603; R_0603_1608Metric; Mouser 603-RC0603FR-0717K8L
R416, R417: 10K_0603; R_0603_1608Metric; Mouser 603-RC0603FR-0710KL
R607: R_DNP_0603; R_0603_1608Metric
U401: SA868; SA8x8

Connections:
+3V3: FB401.2; also elsewhere on the board
+BATT: FB402.1; also elsewhere on the board
/SA8x8/In: R401.2; also elsewhere on the board
/SA8x8/Out: C405.2, R404.1; also elsewhere on the board
/SA8x8/SAAUDIO_ON: Q406.3 (D), R415.2; also elsewhere on the board
/SA8x8/SAHL: R411.2; also elsewhere on the board
/SA8x8/SAPD: U401.6 (PD); also elsewhere on the board
/SA8x8/SAPTT: U401.5 (PTT); also elsewhere on the board
/SA8x8/SARX: U401.16 (RXD); also elsewhere on the board
/SA8x8/SATX: U401.17 (TXD); also elsewhere on the board
Diss: U401.21 (Diss)
Fix1: U401.20 (Fix1)
Fix2: U401.19 (Fix2)
GND: C402.2, C404.2, C405.1, C408.2, C411.1, D402.1 (A), J602.2 (Ext), Q403.2 (S), R402.1, R417.2, U401.9 (Gnd), U401.10 (Gnd); also elsewhere on the board
unnamed: C401.1, C402.1, R402.2, U401.18 (MIC_IN)
unnamed: C401.2, R401.1
unnamed: C404.1, FB401.1, Q406.2 (S), R607.1
unnamed: C408.1, FB402.2, U401.8 (VBAT)
unnamed: C411.2, D402.2 (A), R415.1, R416.1
unnamed: D402.3 (K), R404.2, R416.2, R417.1, U401.3 (AF_OUT)
unnamed: J602.1 (In), U401.12 (ANT)
unnamed: Q403.1 (G), R411.1
unnamed: Q403.3 (D), U401.7 (H/L)
unnamed: Q406.1 (G), R414.1, R607.2
unnamed: R414.2, U401.1 (Audio_ON)

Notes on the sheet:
Copyright 2020 Marc CAPDEVILLE (F4JMZ) This source describes Open Hardware and is licensed under the CERN-OHL-S v2. You may redistribute and modify this source and make products using it under the terms of the CERN-OHL-S v2 or any later version (https://ohwr.org/cern_ohl_s_v2.txt). This source is d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

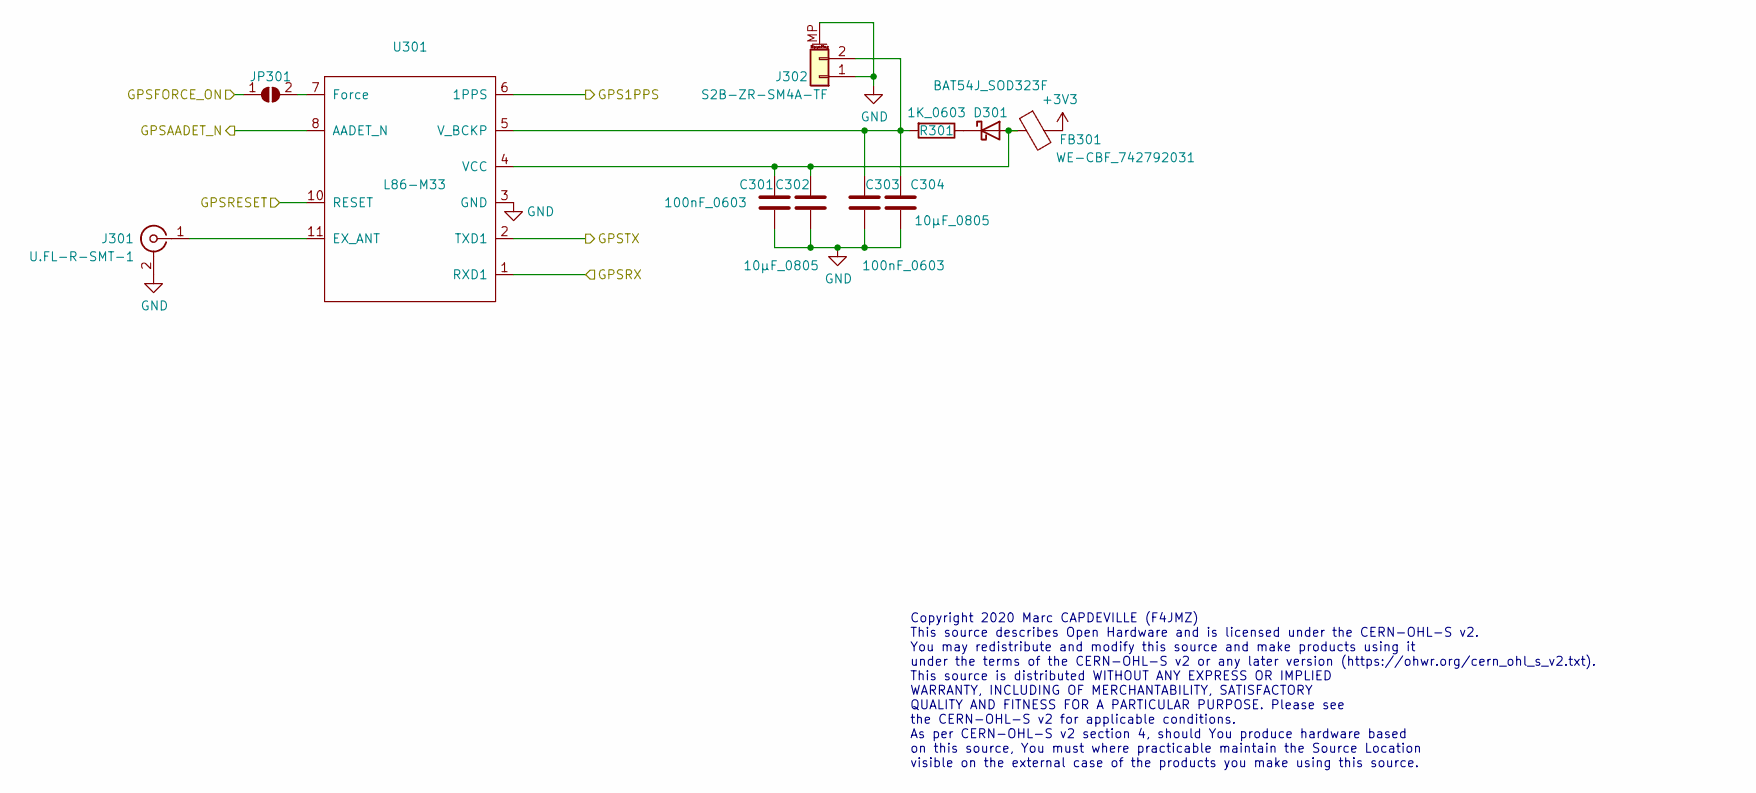
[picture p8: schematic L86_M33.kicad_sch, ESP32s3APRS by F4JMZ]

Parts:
C301, C303: 100nF_0603; C_0603_1608Metric; Mouser 963-UMK107B7104KAHT
C302, C304: 10µF_0805; C_0805_2012Metric; Mouser 963-TMK212BBJ106MG-T
D301: BAT54J_SOD323F; D_SOD-323F; Mouser 771-BAT54J115
FB301: WE-CBF_742792031; L_0805_2012Metric; Mouser 710-742792031
J301: U.FL-R-SMT-1; U.FL_Hirose_U.FL-R-SMT-1_Vertical; Mouser 798-U.FL-R-SMT-110
J302: S2B-ZR-SM4A-TF; JST_S2B-ZR-SM4A-TF_1x02-1MP_P1.50mm_Horizontal; Mouser 306-S2BZRSM4ATFLFSN
JP301: SolderJumper_2_Open; SolderJumper-2_P1.3mm_Open_RoundedPad1.0x1.5mm
R301: 1K_0603; R_0603_1608Metric; Mouser 603-RC0603FR-071KL
U301: L86-M33; XCVR_L86; Mouser 277-L86-M33

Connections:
+3V3: FB301.2; also elsewhere on the board
/E-paper display/PON: JP301.1 (A); also elsewhere on the board
/L86-M33/GPS1PPS: U301.6 (1PPS); also elsewhere on the board
/L86-M33/GPSAADET_N: U301.8 (AADET_N)
/L86-M33/GPSRESET: U301.10 (RESET); also elsewhere on the board
/L86-M33/GPSRX: U301.1 (RXD1); also elsewhere on the board
/L86-M33/GPSTX: U301.2 (TXD1); also elsewhere on the board
GND: C301.2, C302.2, C303.2, C304.2, J301.2 (Ext), J302.1, J302.MP (MountPin), U301.3 (GND), U301.12 (GND); also elsewhere on the board
unnamed: C301.1, C302.1, D301.2 (A), FB301.1, U301.4 (VCC)
unnamed: C303.1, C304.1, J302.2, R301.2, U301.5 (V_BCKP)
unnamed: D301.1 (K), R301.1
unnamed: J301.1 (In), U301.11 (EX_ANT)
unnamed: JP301.2 (B), U301.7 (Force)

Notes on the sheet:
Copyright 2020 Marc CAPDEVILLE (F4JMZ) This source describes Open Hardware and is licensed under the CERN-OHL-S v2. You may redistribute and modify this source and make products using it under the terms of the CERN-OHL-S v2 or any later version (https://ohwr.org/cern_ohl_s_v2.txt). This source is d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

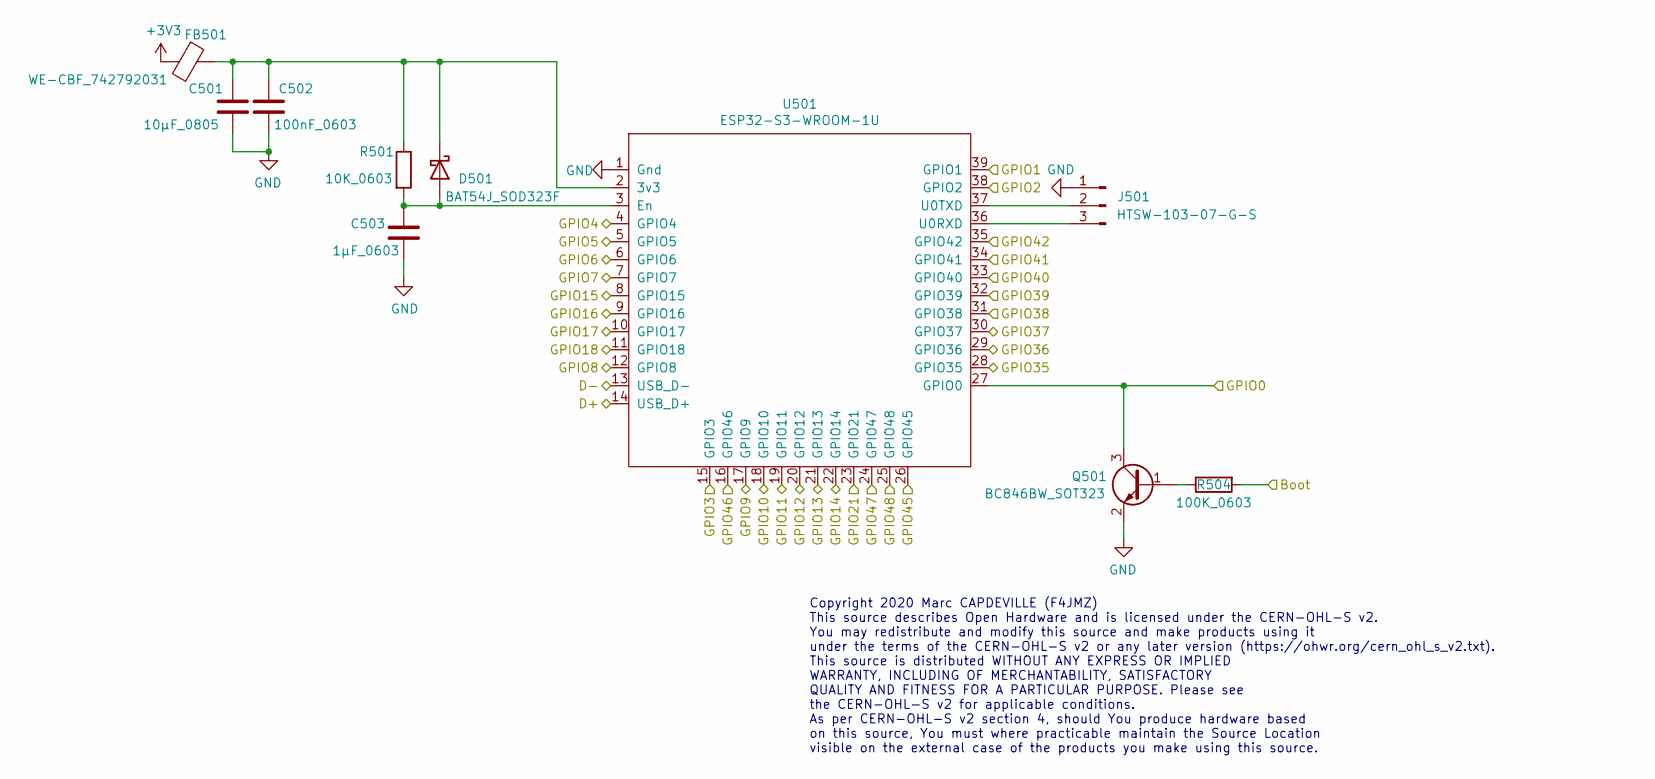
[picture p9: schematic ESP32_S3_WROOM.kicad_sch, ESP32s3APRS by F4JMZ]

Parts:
C501: 10µF_0805; C_0805_2012Metric; Mouser 963-TMK212BBJ106MG-T
C502: 100nF_0603; C_0603_1608Metric; Mouser 963-UMK107B7104KAHT
C503: 1µF_0603; C_0603_1608Metric; Mouser 963-UMK107BJ105KA-T
D501: BAT54J_SOD323F; D_SOD-323F; Mouser 771-BAT54J115
FB501: WE-CBF_742792031; L_0805_2012Metric; Mouser 710-742792031
J501: HTSW-103-07-G-S; PinHeader_1x03_P2.54mm_Vertical; Mouser 200-HTSW10307GS
Q501: BC846BW_SOT323; SOT-323_SC-70; Mouser 771-BC846BW-T/R
R501: 10K_0603; R_0603_1608Metric; Mouser 603-RC0603FR-0710KL
R504: 100K_0603; R_0603_1608Metric; Mouser 603-RC0603FR-07100KL
U501: ESP32-S3-WROOM-1U; Mouser 356-ESP32S3WM1UN16R2

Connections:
+3V3: FB501.2; also elsewhere on the board
/AudioIn: U501.12 (GPIO8); also elsewhere on the board
/BAT_ADC: U501.19 (GPIO11); also elsewhere on the board
/BUSY: U501.31 (GPIO38); also elsewhere on the board
/DC: U501.17 (GPIO9); also elsewhere on the board
/ESP32-S3-WROOM/Boot: R504.2; also elsewhere on the board
/ESP32-S3-WROOM/D+: U501.14 (USB_D+); also elsewhere on the board
/ESP32-S3-WROOM/D-: U501.13 (USB_D-); also elsewhere on the board
/ESP32-S3-WROOM/GPIO0: Q501.3 (C), U501.27 (GPIO0); also elsewhere on the board
/ESP32-S3-WROOM/GPIO1: U501.39 (GPIO1); also elsewhere on the board
/ESP32-S3-WROOM/GPIO4: U501.4 (GPIO4); also elsewhere on the board
/ESP32-S3-WROOM/GPIO5: U501.5 (GPIO5); also elsewhere on the board
/ESP32-S3-WROOM/GPIO6: U501.6 (GPIO6); also elsewhere on the board
/ESP32-S3-WROOM/GPIO7: U501.7 (GPIO7); also elsewhere on the board
/ESP32-S3-WROOM/GPIO15: U501.8 (GPIO15); also elsewhere on the board
/ESP32-S3-WROOM/GPIO16: U501.9 (GPIO16); also elsewhere on the board
/ESP32-S3-WROOM/GPIO17: U501.10 (GPIO17); also elsewhere on the board
/ESP32-S3-WROOM/GPIO18: U501.11 (GPIO18); also elsewhere on the board
/ESP32-S3-WROOM/GPIO40: U501.33 (GPIO40); also elsewhere on the board
/FORCE_ON: U501.16 (GPIO46); also elsewhere on the board
/FSPICS0: U501.18 (GPIO10); also elsewhere on the board
/FSPID: U501.28 (GPIO35); also elsewhere on the board
/FSSPICLK: U501.29 (GPIO36); also elsewhere on the board
/GPS1PPS: U501.22 (GPIO14); also elsewhere on the board
/GPSRESET: U501.32 (GPIO39); also elsewhere on the board
/HL: U501.25 (GPIO48); also elsewhere on the board
/PD: U501.26 (GPIO45); also elsewhere on the board
/Ptt: U501.30 (GPIO37); also elsewhere on the board
/SQ: U501.15 (GPIO3); also elsewhere on the board
/SW1: U501.38 (GPIO2); also elsewhere on the board
/SW2: U501.21 (GPIO13); also elsewhere on the board
/SW3: U501.20 (GPIO12); also elsewhere on the board
/U1RX: U501.23 (GPIO21); also elsewhere on the board
/U1TX: U501.24 (GPIO47); also elsewhere on the board
/U2RX: U501.34 (GPIO41); also elsewhere on the board
/U2TX: U501.35 (GPIO42); also elsewhere on the board
Dis: U501.41 (Dis)
GND: C501.2, C502.2, C503.2, J501.1, Q501.2 (E), U501.1 (Gnd), U501.40 (Gnd); also elsewhere on the board
unnamed: C501.1, C502.1, D501.1 (K), FB501.1, R501.1, U501.2 (3v3)
unnamed: C503.1, D501.2 (A), R501.2, U501.3 (En)
unnamed: J501.2, U501.37 (U0TXD)
unnamed: J501.3, U501.36 (U0RXD)
unnamed: Q501.1 (B), R504.1

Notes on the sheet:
Copyright 2020 Marc CAPDEVILLE (F4JMZ) This source describes Open Hardware and is licensed under the CERN-OHL-S v2. You may redistribute and modify this source and make products using it under the terms of the CERN-OHL-S v2 or any later version (https://ohwr.org/cern_ohl_s_v2.txt). This source is d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

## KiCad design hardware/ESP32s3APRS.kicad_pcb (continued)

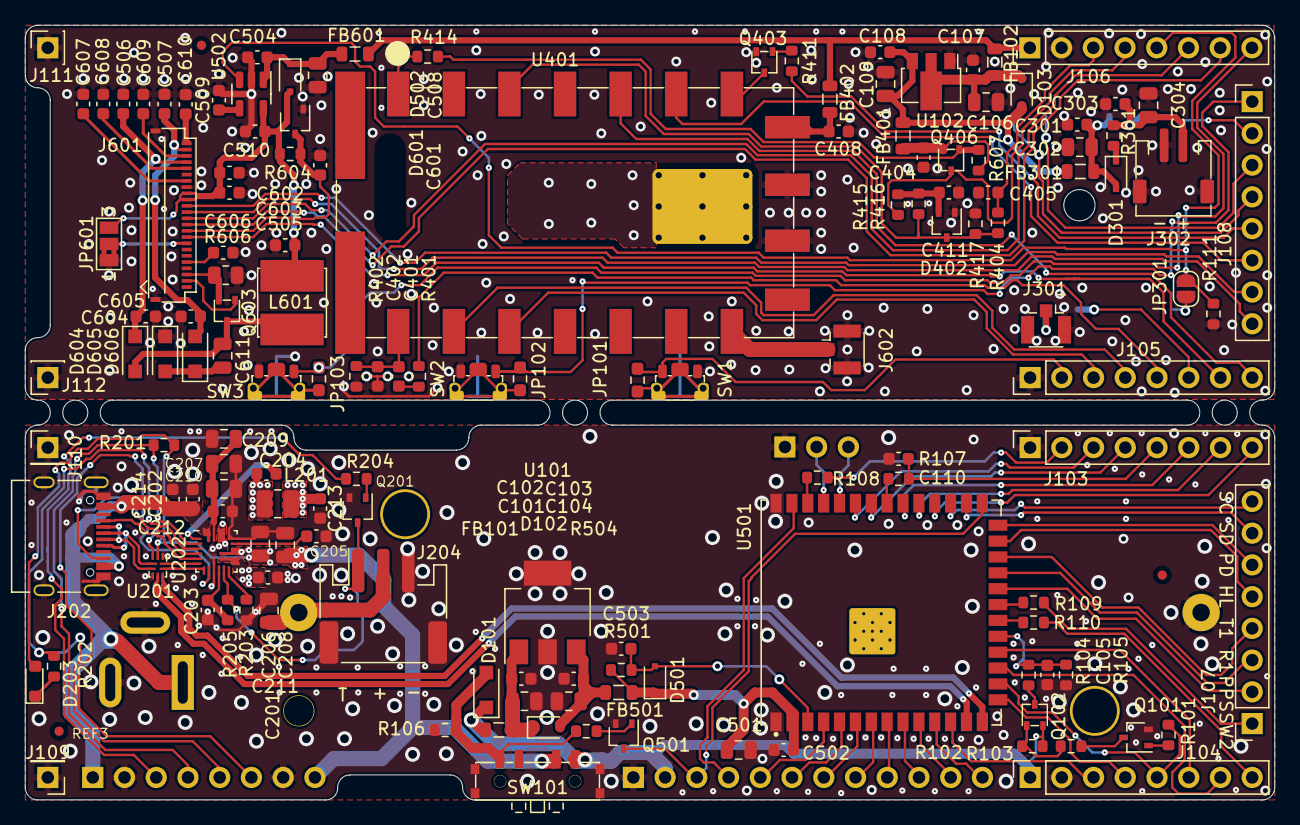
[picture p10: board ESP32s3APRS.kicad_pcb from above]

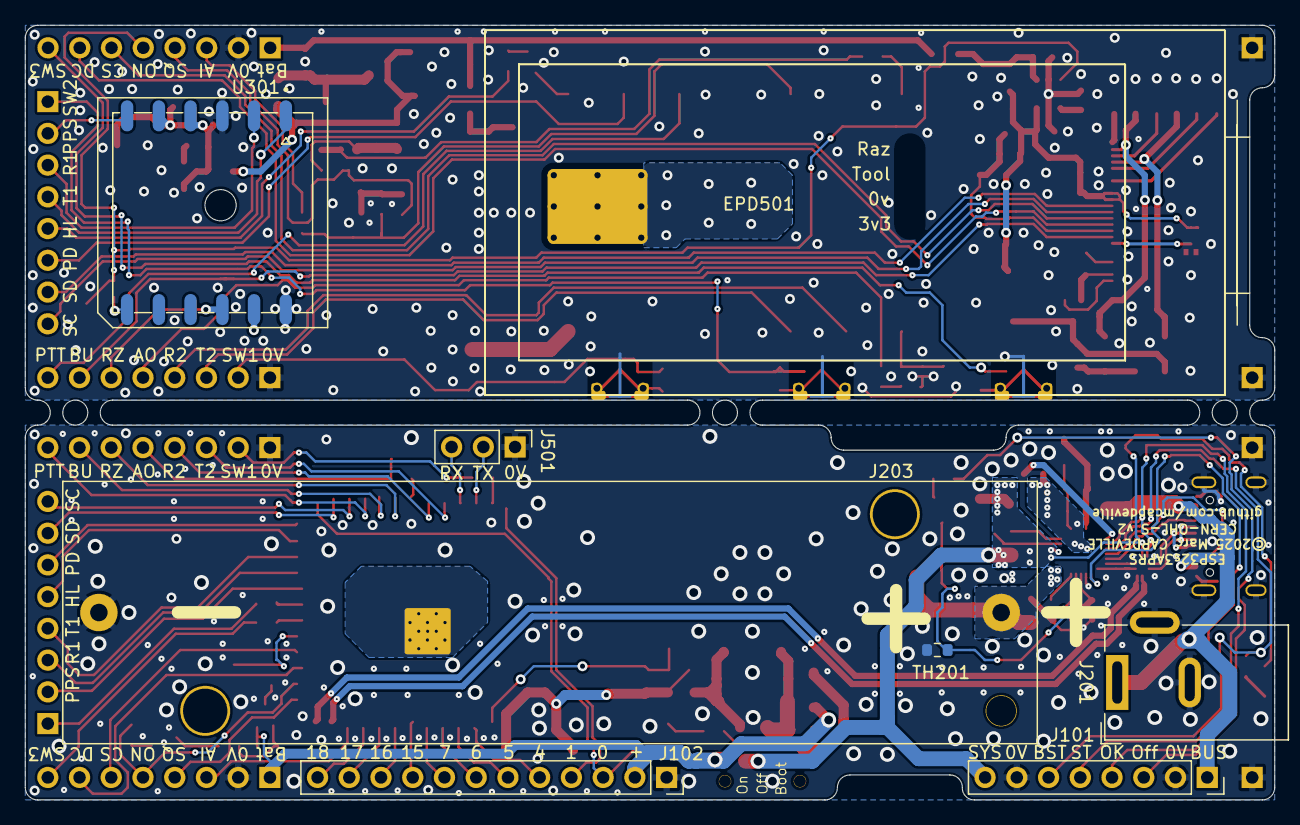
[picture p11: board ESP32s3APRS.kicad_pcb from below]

Board: 2 copper layers, 100.0 x 62.0 mm, 156 parts (8 on the bottom side), 131 nets.

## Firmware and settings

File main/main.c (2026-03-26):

/*
 * SPDX-License-Identifier: GPL-3.0-or-later
 *
 * ESP32s3APRS by F4JMZ
 *
 * main/main.c
 *
 * Copyright (C) 2025  Marc CAPDEVILLE (F4JMZ)
 *
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
 * You should have received a copy of the GNU General Public License
 * along with this program.  If not, see <http://www.gnu.org/licenses/>.
 */

#include <freertos/FreeRTOS.h>
#include <freertos/task.h>

#include <stdio.h>
#include <unistd.h>
#include <fcntl.h>
#include <errno.h>
#include <stdatomic.h>

#include <esp_log.h>
#include <esp_intr_alloc.h>
#include <esp_pm.h>
#include <esp_event.h>
#include <esp_heap_caps.h>
#include "esp_vfs_eventfd.h"
#include <esp_timer.h>
#include <driver/gpio.h>
#include <driver/spi_master.h>
#include <esp_sleep.h>
#include <esp_spiffs.h>
#include <driver/uart.h>
#include <driver/uart_vfs.h>
#include <driver/usb_serial_jtag.h>
#include <driver/usb_serial_jtag_vfs.h>
#include <soc/rtc.h>
#include <soc/rtc_cntl_reg.h>
#include <esp_private/rtc_ctrl.h>
#include "hal/brownout_hal.h"
#include "hal/brownout_ll.h"


#include <ssd1680.h>
#include "xbm/logo.xbm"
#include "xbm/symbols1.xbm"
#include "xbm/symbols2.xbm"
#include <lvgl.h>
#include "xbm_font.h"
#include <SA8x8.h>
#include <nvs_flash.h>
#include <nvs.h>
#include "usb.h"
#include "usb_audio.h"
#include "adc.h"
#include "hmi.h"
#include "gps.h"
#include "afsk_config.h"
#include "modem.h"
#include "modem_afsk1200.h"
#include "kiss.h"
#include "aprs.h"
#include "ax25_phy.h"
#include "ax25_phy_simplex.h"
#include "ax25_lm.h"
#include "framebuff.h"
// #include <lowpower.h>
#include "micropython.h"
#include "usb_cdc.h"

#include "config.h"

#define TAG "MAIN"

ESP_EVENT_DEFINE_BASE(MAIN_EVENT);

#define MAIN_EVENT_RSSI	0
#define MAIN_EVENT_ADC2	1

#define XBM_SWAP_BITS(bitmap) do {\
	for (int i = 0;i<sizeof(bitmap);i++) {\
		uint8_t c;\
		c = bitmap[i];\
		c = ((c&0xf0)>>4) | ((c&0x0f)<<4);\
		c = ((c&0xcc)>>2) | ((c&0x33)<<2);\
		c = ((c&0xaa)>>1) | ((c&0x55)<<1);\
		bitmap[i] = c;\
	}} while (0)

SSD1680_t * Epd;
lv_font_t * Symbols[3];
HMI_t * Hmi;
GPS_t * Gps;
nvs_handle_t Nvs;
SA8x8_t * SA8x8;
Modem_t * Modem_AFSK1200;
Kiss_t *Kiss;
APRS_t * Aprs;
AX25_Phy_t * Ax25_Phy;
AX25_Lm_t * Ax25_Lm;
uint8_t Rssi;
uint8_t Rssi_max;
int Battery;

/*
IRAM_ATTR void brownout_detect_isr(void*) {

	// Clear interrupt
	REG_WRITE(RTC_CNTL_INT_CLR_REG, RTC_CNTL_BROWN_OUT_INT_CLR);

	if (REG_READ(RTC_CNTL_BROWN_OUT_REG) & RTC_CNTL_BROWN_OUT_DET) {
		if (Nvs)
			nvs_commit(Nvs);

		REG_WRITE(RTC_CNTL_BROWN_OUT_REG,
				(0x3ffL << RTC_CNTL_BROWN_OUT_INT_WAIT_S)
				|RTC_CNTL_BROWN_OUT_CLOSE_FLASH_ENA
				| RTC_CNTL_BROWN_OUT_PD_RF_ENA
				| (0x1ffL << RTC_CNTL_BROWN_OUT_RST_WAIT_S)
				| RTC_CNTL_BROWN_OUT_RST_ENA
				//			| RTC_CNTL_BROWN_OUT_RST_SEL
				//			| RTC_CNTL_BROWN_OUT_CNT_CLR
				| RTC_CNTL_BROWN_OUT_ENA);
		REG_WRITE( RTC_CNTL_FIB_SEL_REG, ((CONFIG_BROWNOUT_DET_LVL) & 7));
	}	
	
}
*/

static int Adc2_Voltage[5];

void app_main(void)
{
	char const * Mp_Console;

	int i,ret;
	uint8_t rssi,max_rssi;
	TickType_t now;
	int64_t ready_time, start_time;

	start_time = esp_timer_get_time();
/*
	// lowpower_start()
	// brownout init
    REG_WRITE(RTC_CNTL_BROWN_OUT_REG,
			(15L << RTC_CNTL_BROWN_OUT_INT_WAIT_S)
			//		| RTC_CNTL_BROWN_OUT_CLOSE_FLASH_ENA
			//		| RTC_CNTL_BROWN_OUT_PD_RF_ENA 
			| (0x3ffL << RTC_CNTL_BROWN_OUT_RST_WAIT_S)
			//			| RTC_CNTL_BROWN_OUT_RST_ENA
			//			| RTC_CNTL_BROWN_OUT_RST_SEL
			//			| RTC_CNTL_BROWN_OUT_CNT_CLR
			| RTC_CNTL_BROWN_OUT_ENA);

	REG_WRITE( RTC_CNTL_FIB_SEL_REG, ((BROWNOUT_DET_LVL) & 7));

    ESP_ERROR_CHECK( rtc_isr_register(brownout_detect_isr, NULL, RTC_CNTL_BROWN_OUT_INT_ENA_M, RTC_INTR_FLAG_IRAM) );

    REG_SET_BIT(RTC_CNTL_INT_ENA_REG, RTC_CNTL_BROWN_OUT_INT_ENA_M);
*/

	// GPIO Init
	gpio_install_isr_service(ESP_INTR_FLAG_IRAM | ESP_INTR_FLAG_LEVEL1 | ESP_INTR_FLAG_SHARED);

	// SA8x8 Radio
	SA8x8 = SA8x8_Init(&SA8x8_config);

	// AFSK1200 Modem
	Modem_AFSK1200 = Modem_AFSK1200_Init(SA8x8, &AFSK_Config);

	// Early start of receiver
	Modem_Start_Receiver(Modem_AFSK1200);

	// AX25 stack
	Ax25_Phy = AX25_Phy_Simplex_Init(Modem_AFSK1200);
	Ax25_Lm = AX25_Lm_Init(Ax25_Phy);
	
	// System Event loop init
	esp_event_loop_create_default();

	// Aprs protocol ont top of AX25 link multiplexer
	Aprs = APRS_Init(Ax25_Lm);

	ready_time = esp_timer_get_time();

	Mp_Console = CONFIG_ESP32S3APRS_MICROPYTHON_CONSOLE;

#ifdef CONFIG_ESP_CONSOLE_USB_SERIAL_JTAG
	// Setup USB-JTAG Console
	if (!usb_serial_jtag_is_driver_installed()) {
		ESP_LOGI(TAG,"Initializing USR serial JTAG");
		setvbuf(stdin, NULL, _IONBF, 0);
		if (usb_serial_jtag_driver_install((usb_serial_jtag_driver_config_t *)&usb_serial_jtag_config) != ESP_OK) {
			ESP_LOGE(TAG, "Error initializing serial JTAG console");
			Mp_Console = (char*)"/dev/uart/0";
		} else {
			usb_serial_jtag_vfs_use_driver();
			usb_serial_jtag_vfs_register();
		}
	}
#endif

	// Setup UART Console
	if (!uart_is_driver_installed(CONFIG_ESP_CONSOLE_UART_NUM)) {
		ESP_LOGI(TAG,"Initializing console uart");
		setvbuf(stdin, NULL, _IONBF, 0);
		if (uart_driver_install(CONFIG_ESP_CONSOLE_UART_NUM,
					UART_HW_FIFO_LEN(CONFIG_ESP_CONSOLE_UART_NUM)*2,
					UART_HW_FIFO_LEN(CONFIG_ESP_CONSOLE_UART_NUM)*2,
					0, NULL,
					ESP_INTR_FLAG_IRAM | ESP_INTR_FLAG_LEVEL1 | ESP_INTR_FLAG_SHARED)
				!= ESP_OK) {
			ESP_LOGE(TAG, "Error initializing uart0 driver");
			Mp_Console = (char*)"/dev/ttyACM/0";
		} else {
			if (uart_param_config(CONFIG_ESP_CONSOLE_UART_NUM,&console_uart_config) != ESP_OK) {
				uart_driver_delete(CONFIG_ESP_CONSOLE_UART_NUM);
			} else {
				if (uart_set_pin(CONFIG_ESP_CONSOLE_UART_NUM,
							CONFIG_ESP32S3APRS_CONSOLE_UART_TX_GPIO,
							CONFIG_ESP32S3APRS_CONSOLE_UART_RX_GPIO,
							UART_PIN_NO_CHANGE,
							UART_PIN_NO_CHANGE) != ESP_OK) {
					uart_driver_delete(CONFIG_ESP_CONSOLE_UART_NUM);
				}
			}
		}
	}

	// setup uart vfs driver
	if (uart_is_driver_installed(CONFIG_ESP_CONSOLE_UART_NUM)) {
		uart_vfs_dev_use_driver(CONFIG_ESP_CONSOLE_UART_NUM);
	}

	// Set log level
#if CONFIG_LOG_MASTER_LEVEL
	esp_log_set_level_master(ESP_LOG_WARN);
#endif

	esp_log_level_set("MAIN", ESP_LOG_INFO);
	esp_log_level_set("event", ESP_LOG_INFO);
	esp_log_level_set("nvs", ESP_LOG_INFO);

	esp_log_level_set("SA8X8", ESP_LOG_INFO);
	esp_log_level_set("MODEM_AFSK1200", ESP_LOG_INFO);
	esp_log_level_set("AFSK_Demod", ESP_LOG_INFO);
	esp_log_level_set("AFSK_Mod", ESP_LOG_INFO);
	esp_log_level_set("framebuff", ESP_LOG_INFO);
	esp_log_level_set("AX25_PHY", ESP_LOG_INFO);
	esp_log_level_set("AX25_LM", ESP_LOG_INFO);
	esp_log_level_set("AX25", ESP_LOG_INFO);

	esp_log_level_set("APRS", ESP_LOG_INFO);
	esp_log_level_set("APRS_PARSERS", ESP_LOG_INFO);
	esp_log_level_set("APRS_ENCODER", ESP_LOG_INFO);
	esp_log_level_set("APRS_LOG", ESP_LOG_INFO);
	esp_log_level_set("SB", ESP_LOG_INFO);

	esp_log_level_set("KISS", ESP_LOG_INFO);

	esp_log_level_set("GPS", ESP_LOG_INFO);
	esp_log_level_set("GPS_PARSER", ESP_LOG_INFO);

	esp_log_level_set("USB", ESP_LOG_DEBUG);
	esp_log_level_set("USB_AUDIO", ESP_LOG_DEBUG);
	esp_log_level_set("USB_CDC", ESP_LOG_INFO);

	esp_log_level_set("SSD1680", ESP_LOG_INFO);
	esp_log_level_set("HMI", ESP_LOG_INFO);

	esp_log_level_set("MPY", ESP_LOG_INFO);
	esp_log_level_set("MP_APRS", ESP_LOG_INFO);

	ESP_LOGI(TAG, "Aprs stack started at %ld us since boot (%ld µs)", (long)ready_time, (long)(ready_time-start_time));

	// SPI master Init
	if (ESP_OK != spi_bus_initialize(CONFIG_ESP32S3APRS_SPI_HOST,
				&spi_config,
				SPI_DMA_CH_AUTO)) {
		ESP_LOGE(TAG,"Error initializing spi bus %d",CONFIG_ESP32S3APRS_SPI_HOST);
	}

	// SSD1680 Init
	Epd = SSD1680_Init(CONFIG_ESP32S3APRS_SPI_HOST,
			CONFIG_ESP32S3APRS_FORCE_ON_GPIO,
			CONFIG_ESP32S3APRS_EPD_CS_GPIO,
			CONFIG_ESP32S3APRS_EPD_DC_GPIO,
			CONFIG_ESP32S3APRS_EPD_BUSY_GPIO,
			&epd_config,
			logo_bits);

	Symbols[0] = xbm_font_Init(symbols1_bits, sizeof(symbols1_bits), symbols1_width, symbols1_width,  0xE020, false);
	if (Symbols[0]) {
		Symbols[1] = xbm_font_Init(symbols2_bits, sizeof(symbols2_bits), symbols2_width, symbols2_width,  0xE120, false);
		if (Symbols[1]) {
			Symbols[2] = xbm_font_Init(symbols2_bits, sizeof(symbols2_bits), symbols2_width, symbols2_width, 0xE220, true);
			if (Symbols[2]) {
				Symbols[1]->fallback = (lv_font_t*)Symbols[2];
				Symbols[2]->fallback = (lv_font_t*)LV_FONT_DEFAULT;
			}
			else 
				Symbols[1]->fallback = (lv_font_t*)LV_FONT_DEFAULT;
			Symbols[0]->fallback = Symbols[1];
		} else 
			Symbols[0]->fallback = (lv_font_t*)LV_FONT_DEFAULT;
	} else
		Symbols[0] = (lv_font_t*)LV_FONT_DEFAULT;

	// Initialise SPIFFS
	ret =esp_vfs_spiffs_register(&Spiffs_Config);
	switch (ret) {
		case ESP_FAIL:
			ESP_LOGE(TAG,"Failed to mount or format spiffs partition labeled \"%s\"",Spiffs_Config.partition_label);
			break;
		case ESP_ERR_NOT_FOUND:
			ESP_LOGE(TAG,"Failed to find spiffs parition labeled\"%s\"",Spiffs_Config.partition_label);
			break;
		case ESP_OK:
			size_t total = 0, used = 0;
			ret = esp_spiffs_info(Spiffs_Config.partition_label, &total, &used);
			if (ret || used > total) {
				ESP_LOGE(TAG,"Can't get spiffs info (%s), checking ...",esp_err_to_name(ret));
				ret = esp_spiffs_check(Spiffs_Config.partition_label);
				if (ret != ESP_OK) {
					ESP_LOGE(TAG, "SPIFFS_check() failed (%s), formating ...", esp_err_to_name(ret));
					esp_spiffs_format(Spiffs_Config.partition_label);
				} else {
					ESP_LOGI(TAG, "SPIFFS_check() successful");
				}

				ret = esp_spiffs_info(Spiffs_Config.partition_label, &total, &used);
				if (ret != ESP_OK) {
					ESP_LOGE(TAG,"Error Mounting spiffs partition labeled \"%s\", aborting.",Spiffs_Config.partition_label);
				}
			}
			
			if (!ret)
				ESP_LOGI(TAG, "\"%s\" partition mounted.\n\t\tsize: total: %d, used: %d",
						Spiffs_Config.partition_label,
						total,
						used);
			break;
		default:
			ESP_LOGE(TAG,"Failed to initialize SPIFFS (%s)", esp_err_to_name(ret));
	}
	
	nvs_flash_init();

   	APRS_Load_Config(Aprs);
	nvs_open("Global",NVS_READWRITE,&Nvs);

	// GPS Init
	Gps = GPS_Init(CONFIG_ESP32S3APRS_GPS_UART_NUM, CONFIG_ESP32S3APRS_GPS_BAUD_RATE,
			CONFIG_ESP32S3APRS_GPS_TX_GPIO, CONFIG_ESP32S3APRS_GPS_RX_GPIO, CONFIG_ESP32S3APRS_GPS_RESET_GPIO);

	SA8X8_Load_Config(SA8x8);

	// USB Init
	USB_Init();

	// Kiss protocol on top of AX25 link multiplexer
	Kiss = Kiss_Init(CONFIG_ESP32S3APRS_KISS_PORT, Ax25_Lm);

	// ADC Init
	ADC_Init(ADC_UNIT_2);
	ADC_Config_Channel(CONFIG_ESP32S3APRS_ADC2_BATTERY_GPIO, ADC_ATTEN_DB_12);
	if (CONFIG_ESP32S3APRS_ADC2_CH1_GPIO != -1)
		ADC_Config_Channel(CONFIG_ESP32S3APRS_ADC2_CH1_GPIO, ADC_ATTEN_DB_12);
	if (CONFIG_ESP32S3APRS_ADC2_CH2_GPIO != -1)
		ADC_Config_Channel(CONFIG_ESP32S3APRS_ADC2_CH2_GPIO, ADC_ATTEN_DB_12);
	if (CONFIG_ESP32S3APRS_ADC2_CH3_GPIO != -1)
		ADC_Config_Channel(CONFIG_ESP32S3APRS_ADC2_CH3_GPIO, ADC_ATTEN_DB_12);
	if (CONFIG_ESP32S3APRS_ADC2_CH4_GPIO != -1)
		ADC_Config_Channel(CONFIG_ESP32S3APRS_ADC2_CH4_GPIO, ADC_ATTEN_DB_12);

	// HMI Init
	SSD1680_Set_Orientation(Epd,SSD1680_ORIENTATION_270);
	Hmi = HMI_Init((lv_disp_drv_t*)Epd);
	if (!Hmi)
		ESP_LOGW(TAG,"Error creating HMI");

   	APRS_Open_Db(Aprs,0);
	APRS_Start(Aprs);

#ifdef CONFIG_PM_ENABLE
	esp_pm_configure(&pm_config);
#endif

	// Start micropython shell on second usb-cdc
	mp_start(Mp_Console);

	// Start main loop
	max_rssi=0;
	i=0;
	now = xTaskGetTickCount();
	while (1) {

		// Every Ten second
		if (!(i%10)) {
			// Get RSSI
			SA8x8_GetRssi(SA8x8,&rssi);
			if (rssi>max_rssi)
				max_rssi=rssi;
			Rssi = rssi;

			uint32_t o,i,e,d,s,r;
			o = atomic_exchange(&usb_out_count, 0);
			i = atomic_exchange(&usb_in_count, 0);
			e = atomic_exchange(&modem_encode_count, 0);
			d = atomic_exchange(&modem_decode_count, 0);
			s = atomic_exchange(&radio_sent_count, 0);
			r = atomic_exchange(&radio_receive_count, 0);

			ESP_LOGI(TAG," o = %lu i = %lu, e = %lu, d = %lu, s = %lu, r = %lu", o, i, e, d, s, r);
		}

		// Every minutes
		if (!(i%60)) {
			// Get Battery voltage
			if (Epd) {
				SSD1680_PowerUp(Epd);
				vTaskDelay(10/portTICK_PERIOD_MS);
			}

			if (CONFIG_ESP32S3APRS_ADC2_BATTERY_GPIO != -1) {
				ADC_Read(CONFIG_ESP32S3APRS_ADC2_BATTERY_GPIO, NULL, &Adc2_Voltage[0]);
				Adc2_Voltage[0] <<= 1;
			}
			if (CONFIG_ESP32S3APRS_ADC2_CH1_GPIO != -1)
				ADC_Read(CONFIG_ESP32S3APRS_ADC2_CH1_GPIO, NULL, &Adc2_Voltage[1]);
			if (CONFIG_ESP32S3APRS_ADC2_CH2_GPIO != -1)
				ADC_Read(CONFIG_ESP32S3APRS_ADC2_CH2_GPIO, NULL, &Adc2_Voltage[2]);
			if (CONFIG_ESP32S3APRS_ADC2_CH3_GPIO != -1)
				ADC_Read(CONFIG_ESP32S3APRS_ADC2_CH3_GPIO, NULL, &Adc2_Voltage[3]);
			if (CONFIG_ESP32S3APRS_ADC2_CH4_GPIO != -1)
				ADC_Read(CONFIG_ESP32S3APRS_ADC2_CH4_GPIO, NULL, &Adc2_Voltage[4]);

			if (Epd)
				SSD1680_PowerDown(Epd);

			// Send ADC2 event
			if (CONFIG_ESP32S3APRS_ADC2_BATTERY_GPIO != -1) {
				Battery = Adc2_Voltage[0];
				ESP_LOGI(TAG,"Battery : %d mv",Battery);
			}

			esp_event_post(MAIN_EVENT,MAIN_EVENT_ADC2,&Adc2_Voltage,sizeof(Adc2_Voltage),portMAX_DELAY);

			// Send rssi event
			if (SA8x8) {
				ESP_LOGI(TAG,"Rssi : %d",max_rssi);
				Rssi_max = max_rssi;
				esp_event_post(MAIN_EVENT,MAIN_EVENT_RSSI,&max_rssi,sizeof(rssi),portMAX_DELAY);
				max_rssi=0;
			}
		}

		// Every 30 min + 10s
		if (!((i-10)%(60*30))) {
			// Send status frame
			if (Aprs)
				APRS_Send_Status(Aprs,NULL); // Send current status
		}

#if !defined(NDEBUG)
		if (!((i-15)%(60*1))) {
# if CONFIG_FREERTOS_GENERATE_RUN_TIME_STATS
static char buff[1024];
			// Show runtime stat
			vTaskGetRunTimeStats(buff);
			fwrite(buff,strlen(buff), 1, stdout);
# endif
			// Check heap integrity
			if (!heap_caps_check_integrity_all(true)) {
				ESP_LOGE(TAG,"Heap integrity check fail !");
				abort();
			}
			heap_caps_print_heap_info(0);

# ifdef CONFIG_PM_ENABLE
			// Dumpp pm locks
			esp_pm_dump_locks(stdout);
# endif

# if CONFIG_FREERTOS_USE_TRACE_FACILITY
static TaskStatus_t Task_status[20];
static unsigned long Runtime;
			// Dump task status
			uxTaskGetSystemState(Task_status, sizeof(Task_status)/sizeof(Task_status[0]), &Runtime);
			printf("Id \tName \t MinStackFree\n");
			for (i=0; i< (sizeof(Task_status)/sizeof(Task_status[0])); i++) {
				if (Task_status[i].xTaskNumber)
					printf("%d\t%s\t%lu\n",
							Task_status[i].xTaskNumber, 
							Task_status[i].pcTaskName,
							Task_status[i].usStackHighWaterMark);

			}
# endif
			fflush(stdout);
		}
#endif

		vTaskDelayUntil(&now, 5000/portTICK_PERIOD_MS);
		i+=5;
	}

}

void RTC_IRAM_ATTR esp_wake_deep_sleep(void) {
    esp_default_wake_deep_sleep();
    // Add additional functionality here
}

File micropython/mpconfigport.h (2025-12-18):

/*
 * SPDX-License-Identifier: MIT
 *
 * The MIT License (MIT)
 *
 * Copyright (c) 2025 Marc CAPDEVILLE
 *
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
 * THE SOFTWARE IS PROVIDED "AS IS", WITHOUT WARRANTY OF ANY KIND, EXPRESS OR
 * IMPLIED, INCLUDING BUT NOT LIMITED TO THE WARRANTIES OF MERCHANTABILITY,
 * FITNESS FOR A PARTICULAR PURPOSE AND NONINFRINGEMENT. IN NO EVENT SHALL THE
 * AUTHORS OR COPYRIGHT HOLDERS BE LIABLE FOR ANY CLAIM, DAMAGES OR OTHER
 * LIABILITY, WHETHER IN AN ACTION OF CONTRACT, TORT OR OTHERWISE, ARISING FROM,
 * OUT OF OR IN CONNECTION WITH THE SOFTWARE OR THE USE OR OTHER DEALINGS IN
 * THE SOFTWARE.
 */

// Options to control how MicroPython is built for this port,
// overriding defaults in py/mpconfig.h.

#include <stdint.h>
#include <alloca.h>
#include "esp_system.h"
#include "freertos/FreeRTOS.h"

#include "mpconfigboard.h"

// object representation and NLR handling
#define MICROPY_OBJ_REPR                    (MICROPY_OBJ_REPR_A)
#define MICROPY_NLR_SETJMP                  (1)
#if CONFIG_IDF_TARGET_ESP32C3
#define MICROPY_GCREGS_SETJMP               (1)
#endif

// memory allocation policies
#define MICROPY_ALLOC_PATH_MAX              (32)

// emitters
#if CONFIG_MICROPY_SYS_PATH_ARGV_DEFAULTS
#define MICROPY_PY_SYS_PATH_ARGV_DEFAULTS (1)
#else
#define MICROPY_PY_SYS_PATH_ARGV_DEFAULTS (0)
#define MICROPY_PY_SYS_PATH_DEFAULT CONFIG_MICROPY_SYS_PATH_DEFAULT
#endif

// workaround for xtensa-esp32-elf-gcc esp-2020r3, which can generate wrong code for loops
// see https://github.com/espressif/esp-idf/issues/9130
// this was fixed in newer versions of the compiler by:
//   "gas: use literals/const16 for xtensa loop relaxation"
//   https://github.com/jcmvbkbc/binutils-gdb-xtensa/commit/403b0b61f6d4358aee8493cb1d11814e368942c9
#define MICROPY_COMP_CONST_FOLDING_COMPILER_WORKAROUND (1)

// optimisations
#define MICROPY_OPT_COMPUTED_GOTO           (1)

// Python internal features
#define MICROPY_ENABLE_GC                   (1)
#define MICROPY_ENABLE_EMERGENCY_EXCEPTION_BUF (1)
#define MICROPY_LONGINT_IMPL                (MICROPY_LONGINT_IMPL_MPZ)
#define MICROPY_ERROR_REPORTING             (MICROPY_ERROR_REPORTING_NORMAL)
#define MICROPY_WARNINGS                    (1)
#define MICROPY_FLOAT_IMPL                  (MICROPY_FLOAT_IMPL_DOUBLE)
#define MICROPY_STREAMS_POSIX_API           (1)
#define MICROPY_QSTR_EXTRA_POOL             mp_qstr_frozen_const_pool
#define MICROPY_USE_INTERNAL_ERRNO          (0) // errno.h from xtensa-esp32-elf/sys-include/sys
#define MICROPY_USE_INTERNAL_PRINTF         (0) // ESP32 SDK requires its own printf
#define MICROPY_SCHEDULER_DEPTH             (8)

// control over Python builtins
#define MICROPY_PY_STR_BYTES_CMP_WARN       (1)
#define MICROPY_PY_ALL_INPLACE_SPECIAL_METHODS (1)
#define MICROPY_PY_BUILTINS_HELP_TEXT       esp32_help_text
#define MICROPY_PY_IO_BUFFEREDWRITER        (1)
#define MICROPY_PY_UTIME_MP_HAL             (1)

#if CONFIG_MICROPY_ROM_LEVEL_MINIMUM
#define MICROPY_CONFIG_ROM_LEVEL	    (MICROPY_CONFIG_ROM_LEVEL_MINIMUM)
#endif

// Kconfig controled features
#if CONFIG_MICROPY_ROM_LEVEL_CORE
#define MICROPY_CONFIG_ROM_LEVEL	    (MICROPY_CONFIG_ROM_LEVEL_CORE_FEATURES)
#endif

#if CONFIG_MICROPY_ROM_LEVEL_BASIC
#define MICROPY_CONFIG_ROM_LEVEL	    (MICROPY_CONFIG_ROM_LEVEL_BASIC_FEATURES)
#endif

#if CONFIG_MICROPY_ROM_LEVEL_EXTRA
#define MICROPY_CONFIG_ROM_LEVEL	    (MICROPY_CONFIG_ROM_LEVEL_EXTRA_FEATURES)
#endif

#if CONFIG_MICROPY_ROM_LEVEL_FULL
#define MICROPY_CONFIG_ROM_LEVEL	    (MICROPY_CONFIG_ROM_LEVEL_FULL_FEATURES)
#endif

#if CONFIG_MICROPY_ROM_LEVEL_EVERYTHINGS
#define MICROPY_CONFIG_ROM_LEVEL	    (MICROPY_CONFIG_ROM_LEVEL_EVERYTHINGS)
#endif

#ifdef CONFIG_MICROPY_HW_BOARD_NAME
#define MICROPY_HW_BOARD_NAME CONFIG_MICROPY_HW_BOARD_NAME
#else
#define MICROPY_HW_BOARD_NAME "<default board name>"
#endif

#ifdef CONFIG_MICROPY_HW_MCU_NAME
#define MICROPY_HW_MCU_NAME CONFIG_MICROPY_HW_MCU_NAME
#else
#define MICROPY_HW_MCU_NAME CONFIG_IDF_TARGET
#endif

#if CONFIG_MICROPY_PERSISTENT_CODE_LOAD
#define MICROPY_PERSISTENT_CODE_LOAD (1)
#define MICROPY_MAKE_POINTER_CALLABLE(p) ((void *)((mp_uint_t)(p)))
#endif

#if CONFIG_MICROPY_EMIT_NATIVE_CODE && !CONFIG_IDF_TARGET_ESP32C3
#define MICROPY_EMIT_XTENSAWIN              (1)
#else
#define MICROPY_EMIT_XTENSAWIN (0)
#endif

#if MICROPY_PERISTENT_CODE_LOAD
#warn "PERSISTENT CODE LOAD"
#endif

#if MICROPY_EMIT_XTENSAWIN || MICROPY_PERSISTENT_CODE_LOAD
void *esp_native_code_commit(void *, size_t, void *);
#define MP_PLAT_COMMIT_EXEC(buf, len, reloc) esp_native_code_commit(buf, len, reloc)
#endif


#if CONFIG_MICROPY_THREAD
#define MICROPY_PY_THREAD                   (1)
#define MICROPY_PY_THREAD_GIL               (1)
#define MICROPY_PY_THREAD_GIL_VM_DIVISOR    (32)
#endif

#if CONFIG_MICROPY_BUILTINS_BYTEARRAY
#define MICROPY_PY_BUILTINS_BYTEARRAY	(1)
#endif

#if CONFIG_MICROPY_EXTERNAL_MODULE
#define MICROPY_ENABLE_EXTERNAL_IMPORT        (1)
#endif
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

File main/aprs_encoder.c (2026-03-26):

/*
 * SPDX-License-Identifier: GPL-3.0-or-later
 *
 * ESP32s3APRS by F4JMZ
 *
 * main/aprs_encoder.c
 *
 * Copyright (C) 2025  Marc CAPDEVILLE (F4JMZ)
 *
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
 * You should have received a copy of the GNU General Public License
 * along with this program.  If not, see <http://www.gnu.org/licenses/>.
 */

#include <math.h>

#include <esp_log.h>

#include "aprs.h"
#include "aprs_encoder.h"
#include "framebuff.h"

#define TAG "APRS_ENCODER"

static int APRS_Encode_Ts(APRS_Data_t * Data, uint8_t * ptr, int len);
static int APRS_Encode_Pos(APRS_Data_t * Data, uint8_t * ptr, int len);
static int APRS_Encode_Locator(APRS_Data_t * Data, uint8_t * ptr, int len);
static int APRS_Encode_Altitude(APRS_Data_t * Data, uint8_t * ptr, int len);
static int APRS_Encode_Comment(APRS_Data_t * Data, uint8_t * ptr, int len);
static int APRS_Encode_Beam(APRS_Data_t * Data, uint8_t * ptr, int len);

static int APRS_Encode_Extension(APRS_Data_t * Data, uint8_t * ptr, int len);

int APRS_Encode(APRS_Data_t * Data, Frame_t * Frame) {
	uint8_t *ptr;
	int ret, pos, i;

	if (!Data || !Frame)
		return -1;

	if (Frame->frame_size < APRS_MAX_FRAME_LEN) {
		ESP_LOGE(TAG,"Frame too short for encoding report");
		return -1;
	}

	ptr = Frame->frame;
	pos = 0;

	// encode addresses
	memcpy(ptr,&Data->address[0], 2*sizeof(AX25_Addr_t));
	ptr += 2*sizeof(AX25_Addr_t);
	pos += 2*sizeof(AX25_Addr_t);

	i=1;
	while (!(Data->address[i].ssid & 1)) {
		i++;
		memcpy(ptr, &Data->address[i], sizeof(AX25_Addr_t));
		ptr += sizeof(AX25_Addr_t);
		pos += sizeof(AX25_Addr_t);
	}

	ESP_LOGD(TAG,"Found %d digis",i-1);

	// Set control byte
	*(ptr++) = 0x03;	// UI frame
	pos++;

	// Set PID
	*(ptr++) = 0xf0;
	pos++;

	// Set DIT
	*(ptr++) = Data->type;
	pos++;

	// Set Datas
	switch (Data->type) {
		case APRS_DTI_POS_W_TS:
		case APRS_DTI_POS_W_TS_W_MSG:
			ret = APRS_Encode_Ts(Data, ptr, APRS_MAX_FRAME_LEN-2 - pos);
			if (ret < 0) {
				ESP_LOGE(TAG,"Error encoding timestamp");
				return -1;
			}
			pos += ret;
			ptr += ret;
			/* FALLTHRU */
		case APRS_DTI_POS:
		case APRS_DTI_POS_W_MSG:
			if (!Data->position.latitude && !Data->position.longitude) { // no position information
				ESP_LOGE(TAG,"Can't encode position without latitude/longitude datas.");
				return -1;
			}

			ret = APRS_Encode_Pos(Data, ptr, APRS_MAX_FRAME_LEN-2 - pos);
			if (ret < 0) {
				ESP_LOGE(TAG,"Error encoding position");
				return -1;
			}
			pos += ret;
			ptr += ret;

			if (Data->extension) { // Add data extension
				ret = APRS_Encode_Extension(Data, ptr, APRS_MAX_FRAME_LEN-2 - pos);
				if (ret < 0) {
					ESP_LOGE(TAG,"Error encoding data extension");
					return -1;
				}
				pos += ret;
				ptr += ret;
			}

			if (Data->position.altitude) { // Add altitude
				ret = APRS_Encode_Altitude(Data, ptr, APRS_MAX_FRAME_LEN-2 - pos);
				if (ret < 0) {
					ESP_LOGE(TAG,"Error encoding altitude");
					return -1;
				}
				pos += ret;
				ptr += ret;
			}

			ret = APRS_Encode_Comment(Data, ptr, APRS_MAX_FRAME_LEN-2 - pos);
			if (ret < 0) {
				ESP_LOGE(TAG,"Error encoding comment text");
				return -1;
			}
			pos += ret;
			ptr += ret;

			Frame->frame_len = pos;
			return pos;
		case APRS_DTI_STATUS:
			if (Data->time.day) { // With timestamp
				ret = APRS_Encode_Ts(Data, ptr, APRS_MAX_FRAME_LEN-2 - pos);
				if (ret < 0) {
					ESP_LOGE(TAG,"Error encoding timestamp");
					return -1;	
				}
				pos += ret;
				ptr += ret;
			} else if ((Data->position.latitude || Data->position.longitude) &&	Data->symbol[0] ) { // With locator
				ret = APRS_Encode_Locator(Data, ptr, APRS_MAX_FRAME_LEN-2 - pos);
				if (ret < 0) {
					ESP_LOGE(TAG,"Error encoding locator");
					return -1;	
				}
				pos += ret;
				ptr += ret;

				*(ptr++) = Data->symbol[0];
				*(ptr++) = Data->symbol[1];
				pos += 2;

				if (Data->text[0] || Data->extension == APRS_DATA_EXT_BEAM) { // Add space if status text or beam report
					*(ptr++) = ' ';
					pos++;
				}
			}

			ESP_LOGD(TAG,"%d bytes for comment at pos %d.",APRS_MAX_FRAME_LEN-2-pos, pos);
			ret = APRS_Encode_Comment(Data, ptr, APRS_MAX_FRAME_LEN-2 - pos);
			if (ret < 0) {
				ESP_LOGE(TAG,"Error encoding status text");
				return -1;	
			}
			pos += ret;
			ptr += ret;

			if (Data->extension == APRS_DATA_EXT_BEAM) { // Add beam power/heading
				ret = APRS_Encode_Beam(Data, ptr, APRS_MAX_FRAME_LEN-2 - pos);
				if (ret < 0) {
					ESP_LOGE(TAG,"Error encoding beam power/heading.");
					return -1;	
				}
				pos += ret;
				ptr += ret;
			}

			Frame->frame_len = pos;
			return pos;

		default:
			ESP_LOGE(TAG,"Unimplemented encoder for DTI \"%c\".",Data->type);
			return -1;
	}
}

static int APRS_Encode_Ts(APRS_Data_t * Data, uint8_t * ptr, int len) {
	int pos =0;

	if (Data->type == APRS_DTI_WEATHER) {
		if (len < 8) {
			ESP_LOGE(TAG,"Timestamp need 8 chars for weather report");
			return -1;
		}
		*(ptr++) = (Data->time.month/10) + '0';
		*(ptr++) = (Data->time.month%10) + '0';
		pos = 2;
	} else if (len<7) {
		ESP_LOGE(TAG,"Timestamp need 7 chars");
		return -1;
	}

	if (Data->type == APRS_DTI_STATUS && Data->time.local) {
		ESP_LOGE(TAG,"Time in status report MUST NOT be local time");
		return -1;
	}

	if (Data->type == APRS_DTI_STATUS && Data->time.day == 0) {
		ESP_LOGE(TAG,"Time in status report MUST be DDHHMMz format");
		return -1;
	}

	if (Data->time.day) {
		*(ptr++) = (Data->time.day/10) + '0';
		*(ptr++) = (Data->time.day%10) + '0';
		pos+=2;
	}

	*(ptr++) = (Data->time.hours/10) + '0';
	*(ptr++) = (Data->time.hours%10) + '0';
	*(ptr++) = (Data->time.minutes/10) + '0';
	*(ptr++) = (Data->time.minutes%10) + '0';
	pos += 4;

	if (Data->time.day)
		*(ptr++) = Data->time.local?'/':'z';
	else {
		*(ptr++) = (Data->time.seconds/10) + '0';
		*(ptr++) = (Data->time.seconds%10) + '0';
		*(ptr++) = 'h';
		pos+=2;
	}
	pos += 1;

	return pos;
}
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

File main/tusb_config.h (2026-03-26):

/*
 * SPDX-License-Identifier: GPL-3.0-or-later
 *
 * ESP32s3APRS by F4JMZ
 *
 * main/tusb_config.h
 *
 * Copyright (C) 2025  Marc CAPDEVILLE (F4JMZ)
 *
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
 * You should have received a copy of the GNU General Public License
 * along with this program.  If not, see <http://www.gnu.org/licenses/>.
 */

/*
 * The MIT License (MIT)
 *
 * Copyright (c) 2020 Ha Thach (tinyusb.org)
 * Copyright (c) 2020 Jerzy Kasenberg
 *
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
 */

#ifndef _TUSB_CONFIG_H_
#define _TUSB_CONFIG_H_

#ifdef __cplusplus
extern "C" {
#endif

#include "usb_audio_mono.h"

//--------------------------------------------------------------------
// Common Configuration
//--------------------------------------------------------------------

#define CFG_TUSB_RHPORT0_MODE       (OPT_MODE_DEVICE | OPT_MODE_FULL_SPEED)
#define CFG_TUSB_OS                 OPT_OS_FREERTOS

/* USB DMA on some MCUs can only access a specific SRAM region with restriction on alignment.
 * Tinyusb use follows macros to declare transferring memory so that they can be put
 * into those specific section.
 * e.g
 * - CFG_TUSB_MEM SECTION : __attribute__ (( section(".usb_ram") ))
 * - CFG_TUSB_MEM_ALIGN   : __attribute__ ((aligned(4)))
 */
#ifndef CFG_TUSB_MEM_SECTION
#   define CFG_TUSB_MEM_SECTION
#endif

#ifndef CFG_TUSB_MEM_ALIGN
#   define CFG_TUSB_MEM_ALIGN       TU_ATTR_ALIGNED(4)
#endif

#ifndef CFG_TUD_ENDPOINT0_SIZE
#define CFG_TUD_ENDPOINT0_SIZE      64
#endif

#ifndef CFG_TUSB_DEBUG
#define CFG_TUSB_DEBUG        1
#endif

// Enable Device stack
#define CFG_TUD_ENABLED       1

//------------- CLASS -------------//
#define CFG_TUD_CDC               2
#define CFG_TUD_MSC               0
#define CFG_TUD_HID               0
#define CFG_TUD_MIDI              0
#define CFG_TUD_AUDIO             1
#define CFG_TUD_VENDOR            0

//-------------------------------------------------------------------
// CDC_ACM CLASS DRIVER CONFIGURATION
// ------------------------------------------------------------------

// CDC FIFO size of TX and RX
#define CFG_TUD_CDC_RX_BUFSIZE   (TUD_OPT_HIGH_SPEED ? 512 : 256)
#define CFG_TUD_CDC_TX_BUFSIZE   (TUD_OPT_HIGH_SPEED ? 512 : 256)

// CDC Endpoint transfer buffer size, more is faster
#define CFG_TUD_CDC_EP_BUFSIZE   (TUD_OPT_HIGH_SPEED ? 512 : 64)

//--------------------------------------------------------------------
// AUDIO CLASS DRIVER CONFIGURATION
//--------------------------------------------------------------------

#define CFG_TUD_AUDIO_FUNC_1_DESC_LEN                                TUD_AUDIO_DUPLEX_MONO_DESC_LEN

// How many formats are used, need to adjust USB descriptor if changed
#define CFG_TUD_AUDIO_FUNC_1_N_FORMATS                               1

// Audio format type I specifications
#define CFG_TUD_AUDIO_FUNC_1_MAX_SAMPLE_RATE                         52800    // 24bit/96kHz is the best quality for full-speed, high-speed is needed beyond this
#define CFG_TUD_AUDIO_FUNC_1_N_CHANNELS_TX                           1
#define CFG_TUD_AUDIO_FUNC_1_N_CHANNELS_RX                           1

// 16 bbit 16 in bit slots
#define CFG_TUD_AUDIO_FUNC_1_FORMAT_1_N_BYTES_PER_SAMPLE_TX          2
#define CFG_TUD_AUDIO_FUNC_1_FORMAT_1_RESOLUTION_TX                  16
#define CFG_TUD_AUDIO_FUNC_1_FORMAT_1_N_BYTES_PER_SAMPLE_RX          2
#define CFG_TUD_AUDIO_FUNC_1_FORMAT_1_RESOLUTION_RX                  16

// EP and buffer size - for isochronous EP´s, the buffer and EP size are equal (different sizes would not make sense)
#define CFG_TUD_AUDIO_ENABLE_EP_IN                1

#define CFG_TUD_AUDIO_FUNC_1_FORMAT_1_EP_SZ_IN    TUD_AUDIO_EP_SIZE(CFG_TUD_AUDIO_FUNC_1_MAX_SAMPLE_RATE, CFG_TUD_AUDIO_FUNC_1_FORMAT_1_N_BYTES_PER_SAMPLE_TX, CFG_TUD_AUDIO_FUNC_1_N_CHANNELS_TX)

#define CFG_TUD_AUDIO_FUNC_1_EP_IN_SZ_MAX         TUD_AUDIO_EP_SIZE(CFG_TUD_AUDIO_FUNC_1_MAX_SAMPLE_RATE, CFG_TUD_AUDIO_FUNC_1_FORMAT_1_N_BYTES_PER_SAMPLE_TX, CFG_TUD_AUDIO_FUNC_1_N_CHANNELS_TX)
#define CFG_TUD_AUDIO_FUNC_1_EP_IN_SW_BUF_SZ      CFG_TUD_AUDIO_FUNC_1_EP_IN_SZ_MAX * 4


// EP and buffer size - for isochronous EP´s, the buffer and EP size are equal (different sizes would not make sense)
#define CFG_TUD_AUDIO_ENABLE_EP_OUT               1

#define CFG_TUD_AUDIO_FUNC_1_EP_OUT_SZ_MAX        TUD_AUDIO_EP_SIZE(CFG_TUD_AUDIO_FUNC_1_MAX_SAMPLE_RATE, CFG_TUD_AUDIO_FUNC_1_FORMAT_1_N_BYTES_PER_SAMPLE_RX, CFG_TUD_AUDIO_FUNC_1_N_CHANNELS_RX)
#define CFG_TUD_AUDIO_FUNC_1_EP_OUT_SW_BUF_SZ     CFG_TUD_AUDIO_FUNC_1_EP_OUT_SZ_MAX * 4

// Number of Standard AS Interface Descriptors (4.9.1) defined per audio function - this is required to be able to remember the current alternate settings of these interfaces - We restrict us here to have a constant number for all audio functions (which means this has to be the maximum number of AS interfaces an audio function has and a second audio function with less AS interfaces just wastes a few bytes)
#define CFG_TUD_AUDIO_FUNC_1_N_AS_INT 	          2

// Size of control request buffer
#define CFG_TUD_AUDIO_FUNC_1_CTRL_BUF_SZ	64
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

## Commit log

2025-04-21 Initial commit
    ESP32s3APRS : v0.0.1
    Esp-idf : v5.4.1
    TinyUSB : v0.15.0.2
    Lvgl : release/v8.4
    micropython : v1.25.0
    [ESP32_S3_WROOM.kicad_sch, ESP32s3APRS.kicad_pcb, ESP32s3APRS.kicad_sch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]
2025-05-05 hardware : pcb cleanup
    [ESP32s3APRS.kicad_pcb, ESP32s3APRS.kicad_sch, SA8x8.kicad_sch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]
2025-05-05 SA8x8 : correct power-up sequence
    [SA8x8.c, gpio.c]
2025-12-06 AFSK1200 : Using FIR filter
2025-12-18 Hardware cleanup
    [ESP32_S3_WROOM.kicad_sch, ESP32s3APRS.kicad_sch, L86_M33.kicad_sch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]
2025-12-18 Update IDE to v6.0 and somme fix
    [nvs.csv]
2025-12-23 Use Tinyusb UAC2 feedback method
    Use Tinyusb audio class device feedback methode for OUT EP with explicit
    feedback.
    Read/Write From/to ep fifo is done in USB_AUDIO_Radio_Cb() in Radio task context.
2025-12-23 Use atomic type to count samples
2025-12-23 SA8x8 : use atomic type to count sample
2025-12-23 GPS : fix year representation
    [gps.c]
2026-03-26 [APRS] : Altitude on position fixes
    [aprs_encoder.c]
2026-03-26 [GPS] Some fixes on Altitude and data validation
    [gps.c]
2026-03-26 {MAIN] : fix master log level
    [main.c]
2026-03-26 {sdkconfig.default] Add missing options
    Add options to calc precise clock divisor for adc and i2s
    Add master log level option
2026-03-27 [Hardware] : add BOM file as ESP32s3APRS.csv
    [ESP32s3APRS.csv, SA8x8.kicad_sch]
2026-03-27 [module esp32s3aprs] Add restart() function

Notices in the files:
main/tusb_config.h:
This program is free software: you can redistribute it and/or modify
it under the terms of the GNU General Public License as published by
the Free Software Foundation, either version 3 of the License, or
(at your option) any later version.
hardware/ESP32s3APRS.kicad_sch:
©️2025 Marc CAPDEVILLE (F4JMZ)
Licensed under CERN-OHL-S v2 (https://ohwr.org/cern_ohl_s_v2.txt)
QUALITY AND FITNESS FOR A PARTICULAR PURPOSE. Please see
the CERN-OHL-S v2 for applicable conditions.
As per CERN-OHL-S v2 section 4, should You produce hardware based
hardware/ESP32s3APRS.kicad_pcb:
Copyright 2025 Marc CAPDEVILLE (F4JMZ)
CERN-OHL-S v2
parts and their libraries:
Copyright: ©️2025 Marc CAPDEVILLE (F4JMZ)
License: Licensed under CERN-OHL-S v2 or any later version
